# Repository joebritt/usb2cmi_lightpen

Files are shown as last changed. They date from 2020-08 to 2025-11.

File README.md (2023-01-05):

# usb2cmi_lightpen
Use a USB mouse instead of (or in conjunction with) the lightpen on a Fairlight CMI.

<p align="middle">
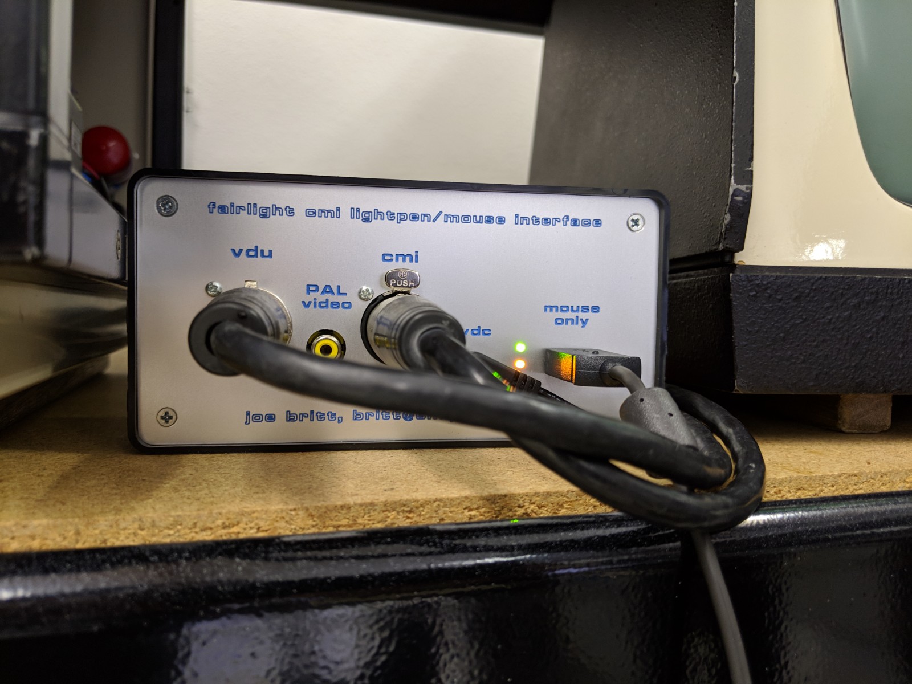
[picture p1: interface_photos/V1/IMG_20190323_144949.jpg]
Version 1
  
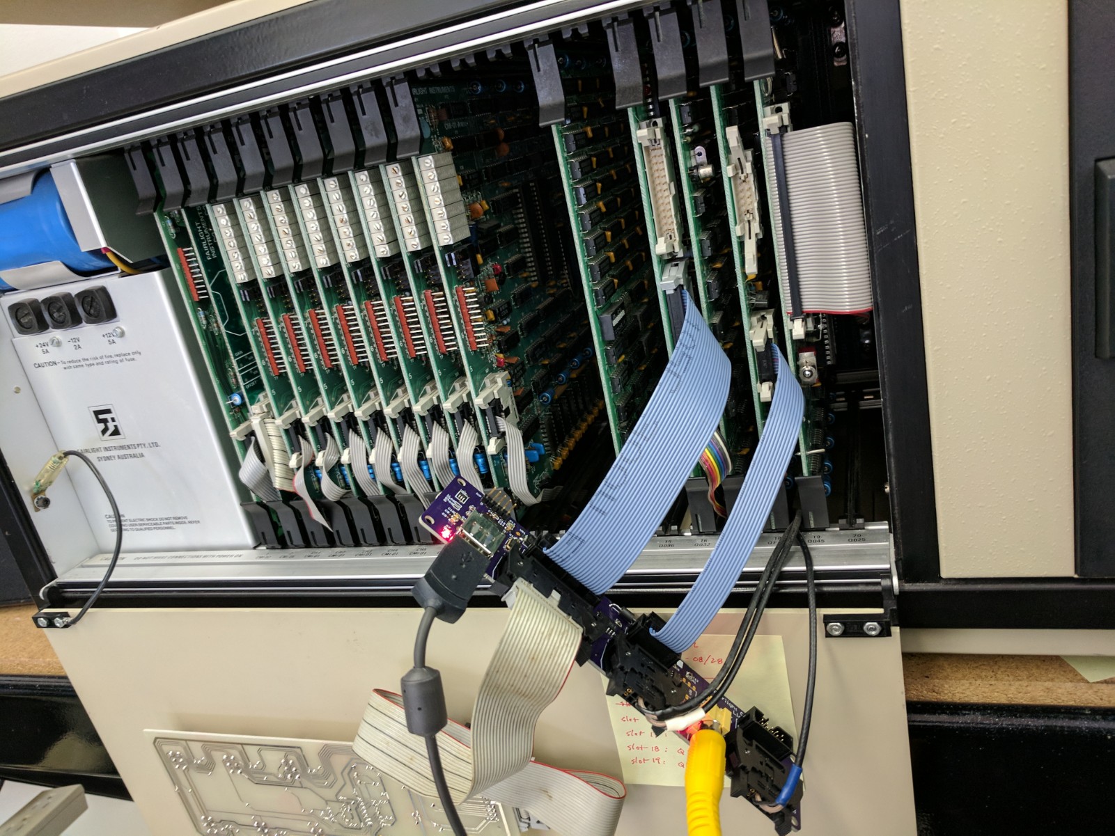
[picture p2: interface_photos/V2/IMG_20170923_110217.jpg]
  
</p>

# Basic Idea

The interface generates lightpen emulation signals that make the CMI video hardware "think" a lightpen is there. The signals are generated to create a small (smaller than is normal with the real lightpen) cursor on the screen.

Moving the mouse, you will see the on-screen cursor track the mouse movement.

Clicking the left button (or button, if it's a 1-button mouse) is like touching the tip of the real lightpen.

If the mouse has a right button, clicking it will toggle the cursor off and on.

If a real lightpen is fitted to the VDU, it will continue to work in conjunction with the mouse.
Normally, the mouse cursor will be shown on the screen. If you bring the lightpen to the screen,
the lightpen cursor will appear and the mouse cursor will disappear. You can then interact using
the lightpen as normal. When you move the lightpen away from the screen, the mouse cursor will
reappear.

# Version 1
[Version 1 PCB](https://oshpark.com/shared_projects/1uISLCAx)</br>

V1 is the original external box style interface. It is powered by a 5V AC adapter.

Both versions have 2 LEDs. These are used to show the status of the video signal (flashes if no video
detected) and presence of a mouse (off if no mouse detected).

V1 has an RCA jack which provides unbuffered access to the CMI video signal. Since it is
unbuffered, the legacy VDU cannot (normally) be used at the same time as the RCA jack.
(V2 buffers the video signal to allow this use case.)

# Version 2
[Version 2 PCB](https://oshpark.com/shared_projects/5qV4mRA7)</br>

V2 is an updated version that fits completely inside the CMI. It is the same core hardware design.

Differences:
  - No AC power supply needed, it is powered from 5V that is tapped from the CMI front panel board
  - RCA jack provides a buffered CMI video signal, so it and the VDU may be used simultaneously
  - Video RCA jack and USB connector are routed to a panel that mounts to the CMI bottom pan
  - laser-cut "wings" attach to the interface board and let it occupy an unused CMI slot

The CMI Series I and II have a slightly different connection to the front panel board. On those
machines, an adapter board is used to convert to a IIX-style connector that the interface board
can connect to.

<p align="middle">
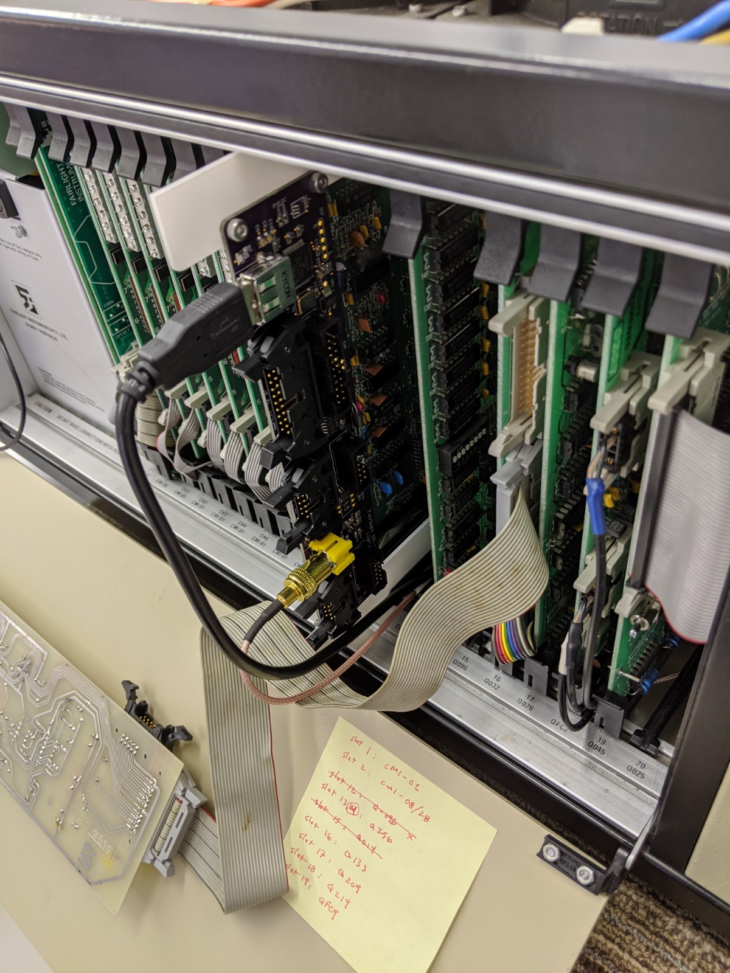
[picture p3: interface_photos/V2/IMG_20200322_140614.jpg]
  
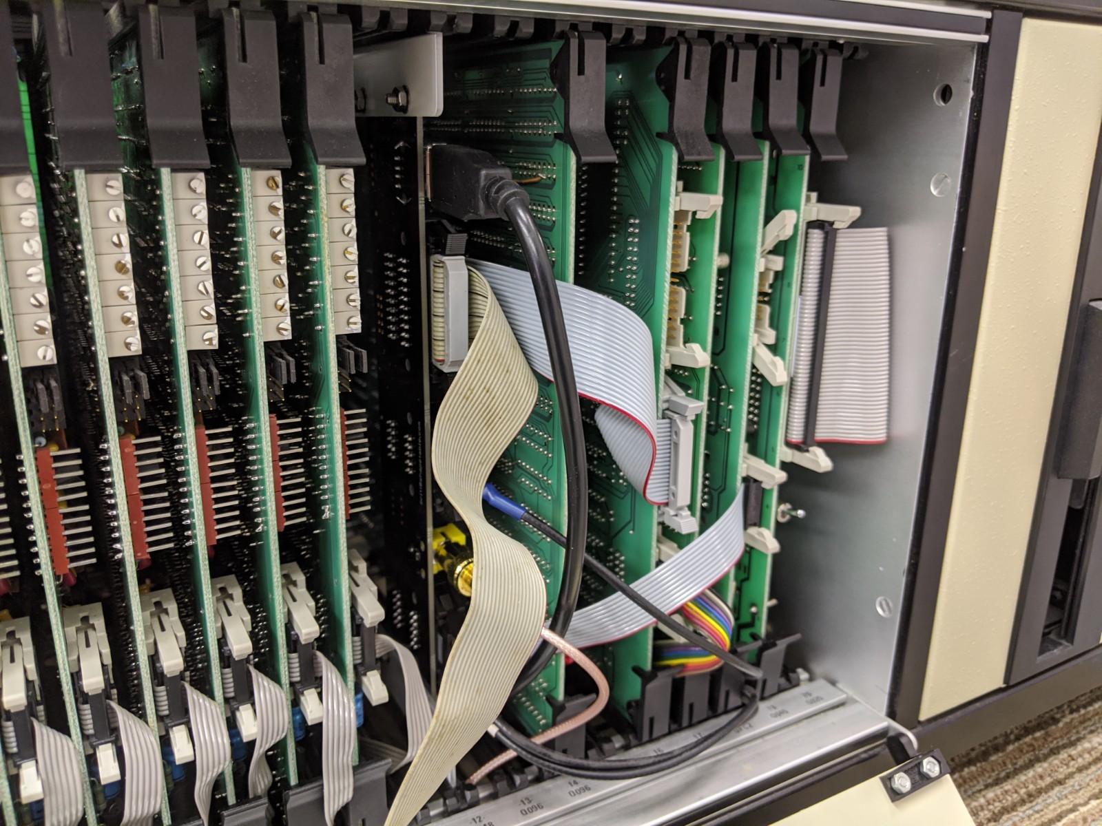
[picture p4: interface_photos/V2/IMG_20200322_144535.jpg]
  
</p>

## Firmware

Some work will be needed to get the code to build with the latest Microchip MPLAB X tools,
so I recommend installing the v8.63 release of MPLAB (pre-MPLAB X). 

Microchip is good about making legacy tools available, you can find version 8.63 here:

https://www.microchip.com/development-tools/pic-and-dspic-downloads-archive

*You don't have to build the code from source:*

In the "prebuilt_hexfiles" folder are pre-compiled images of the bootloader and lightpen emulation application.

To use these:

- Use the Microchip tools to flash bootloader.hex into the PIC32.
- Put cmimouse.hex on a USB thumbdrive (formatted with a DOS/FAT filesystem).
- Plug the thumbdrive into the interface USB port and power up the board.
- You should see the leds blink back and forth, then the cmimouse.hex file will be copied from the thumbdrive to the PIC32 flash.
- You'll see the LEDs change their flashing pattern when the code is flashed and started.
- Unplug the thumbdrive, plug in a mouse, and you should see the mouse status LED turn ON.
- If you connect the unit to the CMI and power on the CMI, you should see the video status LED stop flashing and go solid ON, and the cursor appear on the CMI video output.

## Hardware

The PCB design tool Eagle was used for all PCBs. 
The Eagle .brd files can be easily uploaded to OSHPark (https://oshpark.com/) for fabrication. Of course, you can use any board house you like to make them.
All boards are 2 layer, 6mil minimum trace/space, and 10mil minimum drill.

The aluminum front panel (for Version 1) and the aluminum rear panel (for Version 2) were designed using Front Panel Designer and fabricated using Front Panel Express (https://www.frontpanelexpress.com/).
Eagle was used as a crude 2D mechanical CAD for the Version 2 rear panel and the Version 2 mounting wings. 
Board files and generated PDFs and XPS files for these are included. The XPS files were used to drive a laser cutter to make prototypes of the rear panel and to make the actual mounting wings.

## Cabling

### Version 1

The 5-pin XLR cable from the CMI to the monitor ("VDU" in Fairlight parlance) connects
to the box. This cable carries a monochrome composite video signal with PAL timing from the CMI
and 2 TTL level signals from the lightpen to the CMI. 

These 3 signals are carried over 3x 75 ohm coax cables bundled together and sheathed similar to
an analog RGB video cable. The pinout for this cable is not straight-through, please see the
details in the monitor_cable folder.

Using two of these 5-pin XLR cables, the box is connected between the CMI and VDU.
Of course, the box can be used without the VDU, in which case only one 5-pin XLR cable is needed.

### Version 2

Version 2 doesn't need the external 5-pin XLR cabling, but does need several smaller internal cables:

- 1x 26-way ribbon cable with a female IDC connector at each end, taps power from CMI front panel
- 1x (CMI IIX) or 2x (CMI I or II) 10-way ribbon cable with a female IDC connector at each end for video & LP signals
- 1x USB Type A to Type B bulkead connector extension, routes USB connection on board to rear panel
- 1x RCA male/male extension, routes video from RCA jack on board to rear panel RCA jack
- 1x RCA female/female bulkhead connector, pass video from internal extension cable to external jack

## Mounting Hardware

### Version 1

The plastic box that was used for Version 1 is off-the-shelf from Radio Shack. It appears that they
still carry this box: https://www.radioshack.com/products/radioshack-project-enclosure-6x3x2?variant=20332261445

The aluminum front panel is designed to replace the blank aluminum panel that comes with the box.

The PCB attaches to the aluminum front panel with the 4 XLR connector screws and floats inside the box.

### Version 2

The 2 laser-cut plastic wings attach to the PCB with 4x M3 screws, nuts, and lockwashers. There are 2 versions
of the wings -- I thought the originals were a little too long, so I made a version 1cm shorter. Both work fine, but the longer ones may cause the internal USB connector to rub against the inside of the front panel door.

For the rear panel, countersunk holes are provided in the aluminum panel to accept the screws originally used to hold the Fairlight factory-provided blank cover panel. Remove the blank panel, use the screws and nuts to affix the new aluminum video/USB jack panel.

The bulkhead female/female RCA connector has 1 large nut which should be on the inside face of the panel.
The bulkhead USB connector has 2 M3 screws that hold it in place.

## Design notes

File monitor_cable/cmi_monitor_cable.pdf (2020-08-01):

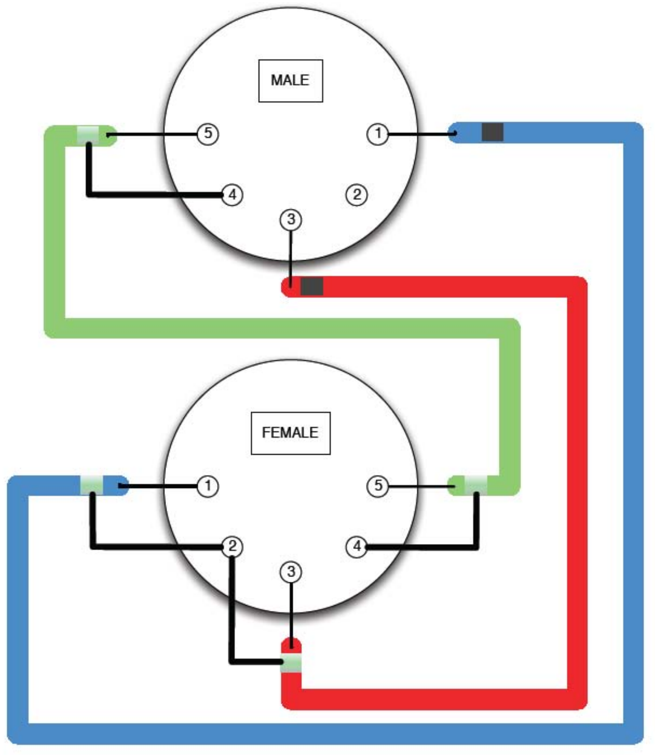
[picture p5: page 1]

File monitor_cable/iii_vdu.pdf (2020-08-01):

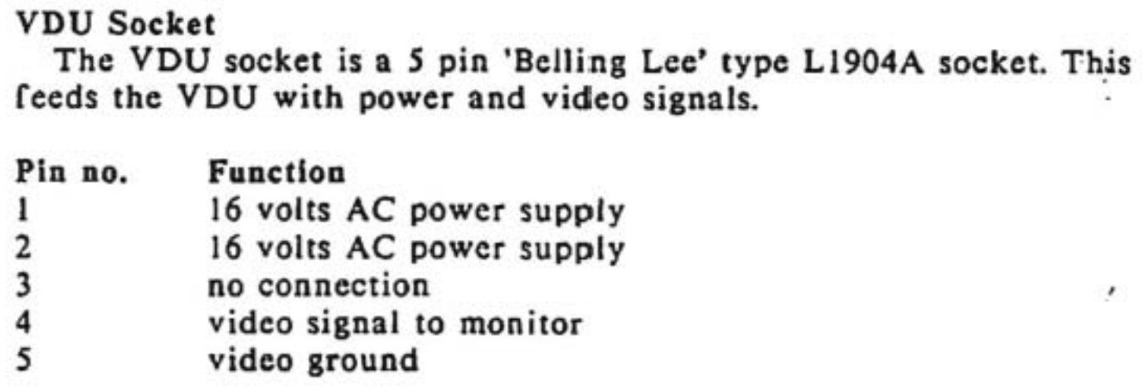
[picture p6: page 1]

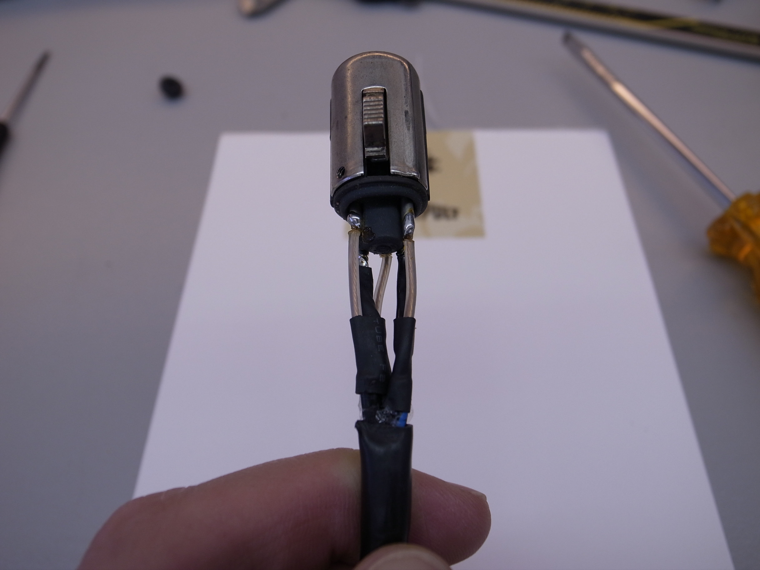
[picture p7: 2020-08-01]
monitor_cable/F_XLR5_BRITT_2.jpg

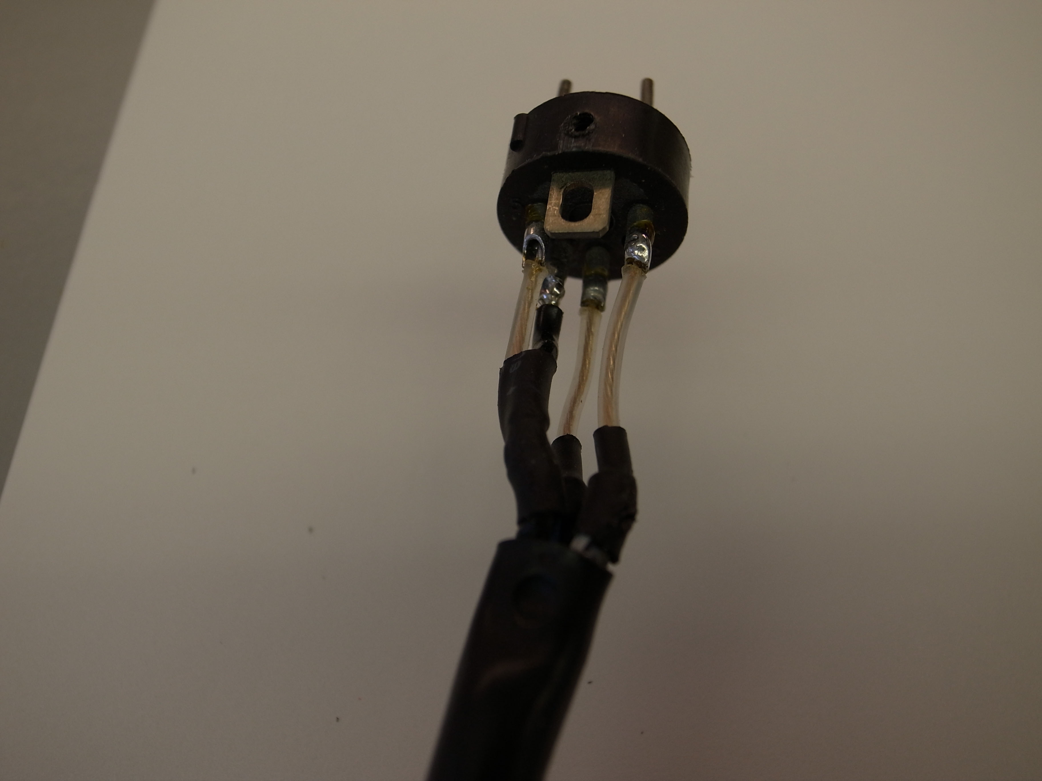
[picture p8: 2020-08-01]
monitor_cable/M_XLR5_BRITT_2.jpg

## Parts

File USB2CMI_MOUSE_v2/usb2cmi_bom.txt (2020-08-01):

	total boards:	20						
								
shortfall	on hand	total	per board					
		Qty	Qty	Value	Device	Parts	supplier	NOTES
11	9	20	1		L-US0207/15	FB1	HSC	
0	20	20	1		MA20-2 *NOTE*	EXP	personal surplus	"mount 2x 5 pin header at pin 1, cut down longer ones"
116	84	200	10	.1uF	C_0603	"C1, C2, C3, C4, C5, C6, C9, C10, C11, C21"	HSC	
0	28	20	1	0	R_0603	R16	HSC	
11	9	20	1	1N4002	1N4002	D1	HSC	
16	4	20	1	8 MHz	CTS-OSC	X1	Mouser	
0	29	20	1	10K	R_0603	R12	HSC	
0	80	40	2	33uF	CPOL-US085CS-1AR	"C7, C22"	personal surplus	
0	29	20	1	51	R_0603	R7	HSC	
0	29	20	1	56	R_0603	R6	HSC	
16	4	20	1	74LS00D	74LS00D	U2	"HSC, Mouser"	
20	0	20	1	100uF	CPOL-USCT6032	C8	Mouser	
0	57	40	2	220	R_0603	"R3, R5"	HSC	
0	57	40	2	330	R_0603	"R2, R4"	HSC	
20	0	20	1	680K	R_0603	R1	HSC	
0	59	20	1	DANGER_POWER	DANGER_POWER	J4	personal surplus	
0	34	20	1	HSC_STACKED	HSC_STACKED	LED1	HSC	
								
20	0	20	1	LM1881SO	LM1881SO	U3B	"Jameco, Digikey, Mouser"	
6	14	20	1	LT1963A-3.3	LINEAR-REG-SOT223	VR1	Digikey	LT1963AEST-3.3#PBF-ND
11	9	20	1	NC5FAH	NC5FAH	J2		
11	9	20	1	NC5MBH	NC5MBH	J1		
12	8	20	1	PIC32MX440FH	PIC32MX440FH	U1		
0	24	20	1	RCA-HSC	RCA-HSC	J3		
0	34	20	1	RJ11	RJ11	ICP		
								
20	0	20	1	TPS2051BDBV	TPS2041BDBV	U5B	Mouser	
20	0	20	1	USB-A-H	USB-A-H	J5

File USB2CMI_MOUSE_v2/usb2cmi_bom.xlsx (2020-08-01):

per board
Qty | digikey | Value | Device | Parts | NOTES
1 |  |  | L-US0207/15 | FB1
10 | 490-5881-1-ND (http://www.digikey.com/scripts/DkSearch/dksus.dll?Detail&itemSeq=226131515&uq=636285868996329209) | .1uF | C_0603 | C1, C2, C3, C4, C5, C6, C9, C10, C11, C21
3 | 311-0.0GRCT-ND (http://www.digikey.com/scripts/DkSearch/dksus.dll?Detail&itemSeq=226131532&uq=636285868996329209) | 0 | R_0603 | R16, R8, R9
1 | CTX301LVCT-ND (http://www.digikey.com/scripts/DkSearch/dksus.dll?Detail&itemSeq=226131551&uq=636285868996329209) | 8 MHz | CTS-OSC | X1
1 | P10KAGCT-ND (http://www.digikey.com/scripts/DkSearch/dksus.dll?Detail&itemSeq=226131872&uq=636285875494800644) | 10K | R_0603 | R12
2 |  | 33uF | CPOL-US085CS-1AR | C7, C22
2 | P56GCT-ND (http://www.digikey.com/scripts/DkSearch/dksus.dll?Detail&itemSeq=226131893&uq=636285875946559209) | 56 | R_0603 | R6, R7
1 | 296-14873-1-ND (http://www.digikey.com/scripts/DkSearch/dksus.dll?Detail&itemSeq=226131851&uq=636285874587879961) | 74LS00D | 74LS00D | U2
1 |  | 100uF | CPOL-USCT6032 | C8
2 | P220GCT-ND (http://www.digikey.com/scripts/DkSearch/dksus.dll?Detail&itemSeq=226131961&uq=636285877032814430) | 220 | R_0603 | R3, R5
2 | P330GCT-ND (http://www.digikey.com/scripts/DkSearch/dksus.dll?Detail&itemSeq=226131964&uq=636285877272659209) | 330 | R_0603 | R2, R4
1 | P680KGCT-ND (http://www.digikey.com/scripts/DkSearch/dksus.dll?Detail&itemSeq=226131969&uq=636285877573828526) | 680K | R_0603 | R1
1 | 609-4616-1-ND (http://www.digikey.com/scripts/DkSearch/dksus.dll?Detail&itemSeq=226131568&uq=636285868996339209) | FCI 10118193-0001LF | Micro USB | J4
1 | 350-1823-ND (http://www.digikey.com/scripts/DkSearch/dksus.dll?Detail&itemSeq=226131790&uq=636285874161180812) | 5530123F | Dialight 2 high LED | LED1
1 | LM1881N/NOPB-ND (http://www.digikey.com/scripts/DkSearch/dksus.dll?Detail&itemSeq=226131589&uq=636285870148726090) | LM1881SO | LM1881SO | U3B
1 | LT1963AEST-3.3#TRPBFCT-ND (http://www.digikey.com/scripts/DkSearch/dksus.dll?Detail&itemSeq=226131603&uq=636285870685653294) | LT1963A-3.3 | LINEAR-REG-SOT223 | VR1 | LT1963AEST-3.3#PBF-ND/ cheaper one is AME
1 |  | NC5FAH | NC5FAH | J2
1 |  | NC5MBH | NC5MBH | J1
1 | PIC32MX440F128H-80I/PT-ND (http://www.digikey.com/scripts/DkSearch/dksus.dll?Detail&itemSeq=226131780&uq=636285873862370934) | PIC32MX440FH | PIC32MX440FH | U1
1 | CP-1421-ND (http://www.digikey.com/scripts/DkSearch/dksus.dll?Detail&itemSeq=226131634&uq=636285871022663475) | RCJ-044 | CUI RCA | J3
1 | 553-2258-ND (http://www.digikey.com/scripts/DkSearch/dksus.dll?Detail&itemSeq=226131638&uq=636285871313076030) | E5566-Q0LK22-L | PULSE RJ11 | ICP
1 |  |  | MA20-2 *NOTE* | EXP | mount 2x 5 pin header at pin 1, cut down longer ones
1 |  | TPS2051BDBV | TPS2041BDBV | U5B
1 |  | USB-A-H | USB-A-H | J5
1 |  | radio shack case

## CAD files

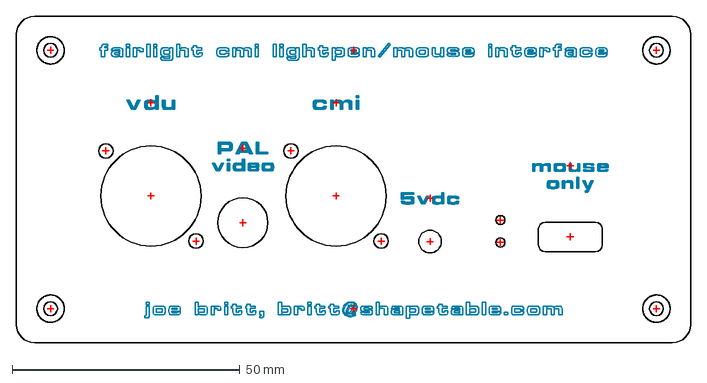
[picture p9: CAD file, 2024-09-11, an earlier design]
USB2CMI_MOUSE_v1/USB2CMI_log.dxf
148.0 x 71.7 mm

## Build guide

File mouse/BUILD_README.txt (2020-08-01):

Building USB Mouse -> CMI Lightpen adapter code
Joe Britt, August 2010

BUILDING FOR/WITH BOOTLOADER
----------------------------

Build the bootloader project (Release build) and flash into PIC32440MX128H
using ICD3 or equivalent.

Build the mouse project (Release build).  Do not flash.  Switch to command
(DOS) window and go to the mouse\Output directory.

type:

pic32-bin2hex -v cmi_mouse.elf

then type:

rename cmi_mouse.hex cmimouse.hex

then copy cmimouse.hex to your USB thumbdrive.

Plug USB thumbdrive into usb2cmi mouse adapter USB port, and power cycle the
usb2cmi board.  You will see the yellow light flicker as the mouse application
is programmed into the application partition.  When it finishes, it will
start the mouse application.

BUILDING STANDALONG (NO BOOTLOADER)
-----------------------------------

Open the mouse project and remove the 2 Linker Script files (in the IDE).
Build and load onto the usb2cmi board with an ICD3 or equivalent.

Debug/run.

Note that this will overwrite the bootloader, so you will need to build
and re-flash it if you want/need to use it again.

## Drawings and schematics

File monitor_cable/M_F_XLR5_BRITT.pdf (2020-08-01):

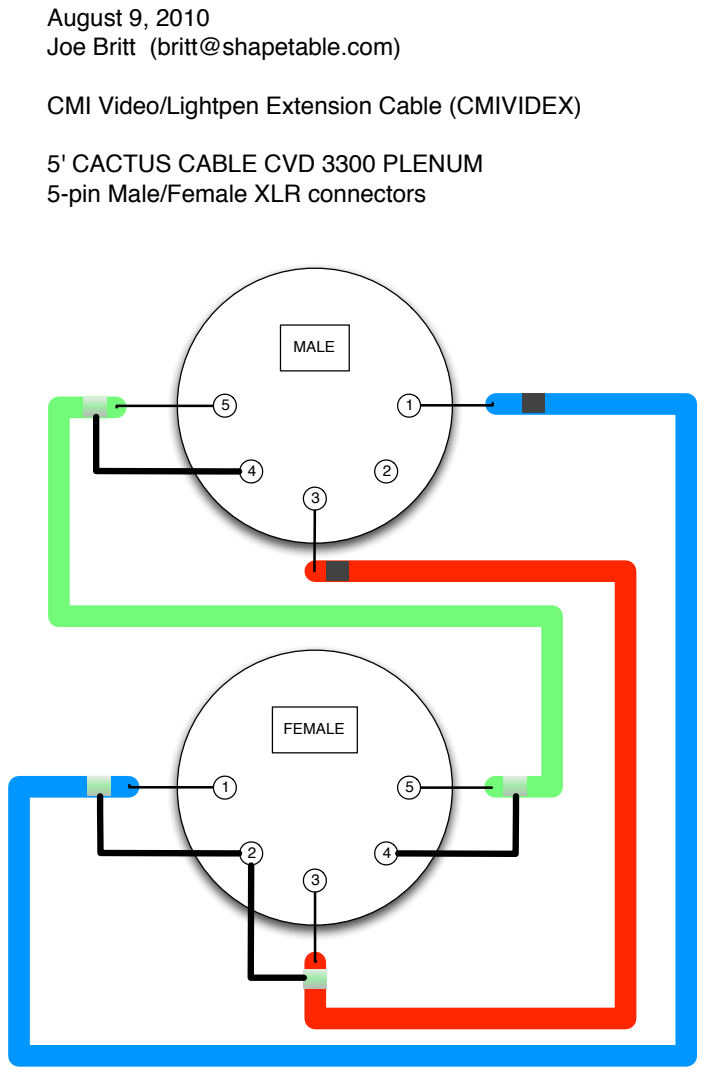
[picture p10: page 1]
MALE; FEMALE

August 9, 2010
Joe Britt (britt@shapetable.com)

CMI Video/Lightpen Extension Cable (CMIVIDEX)

5' CACTUS CABLE CVD 3300 PLENUM
5-pin Male/Female XLR connectors

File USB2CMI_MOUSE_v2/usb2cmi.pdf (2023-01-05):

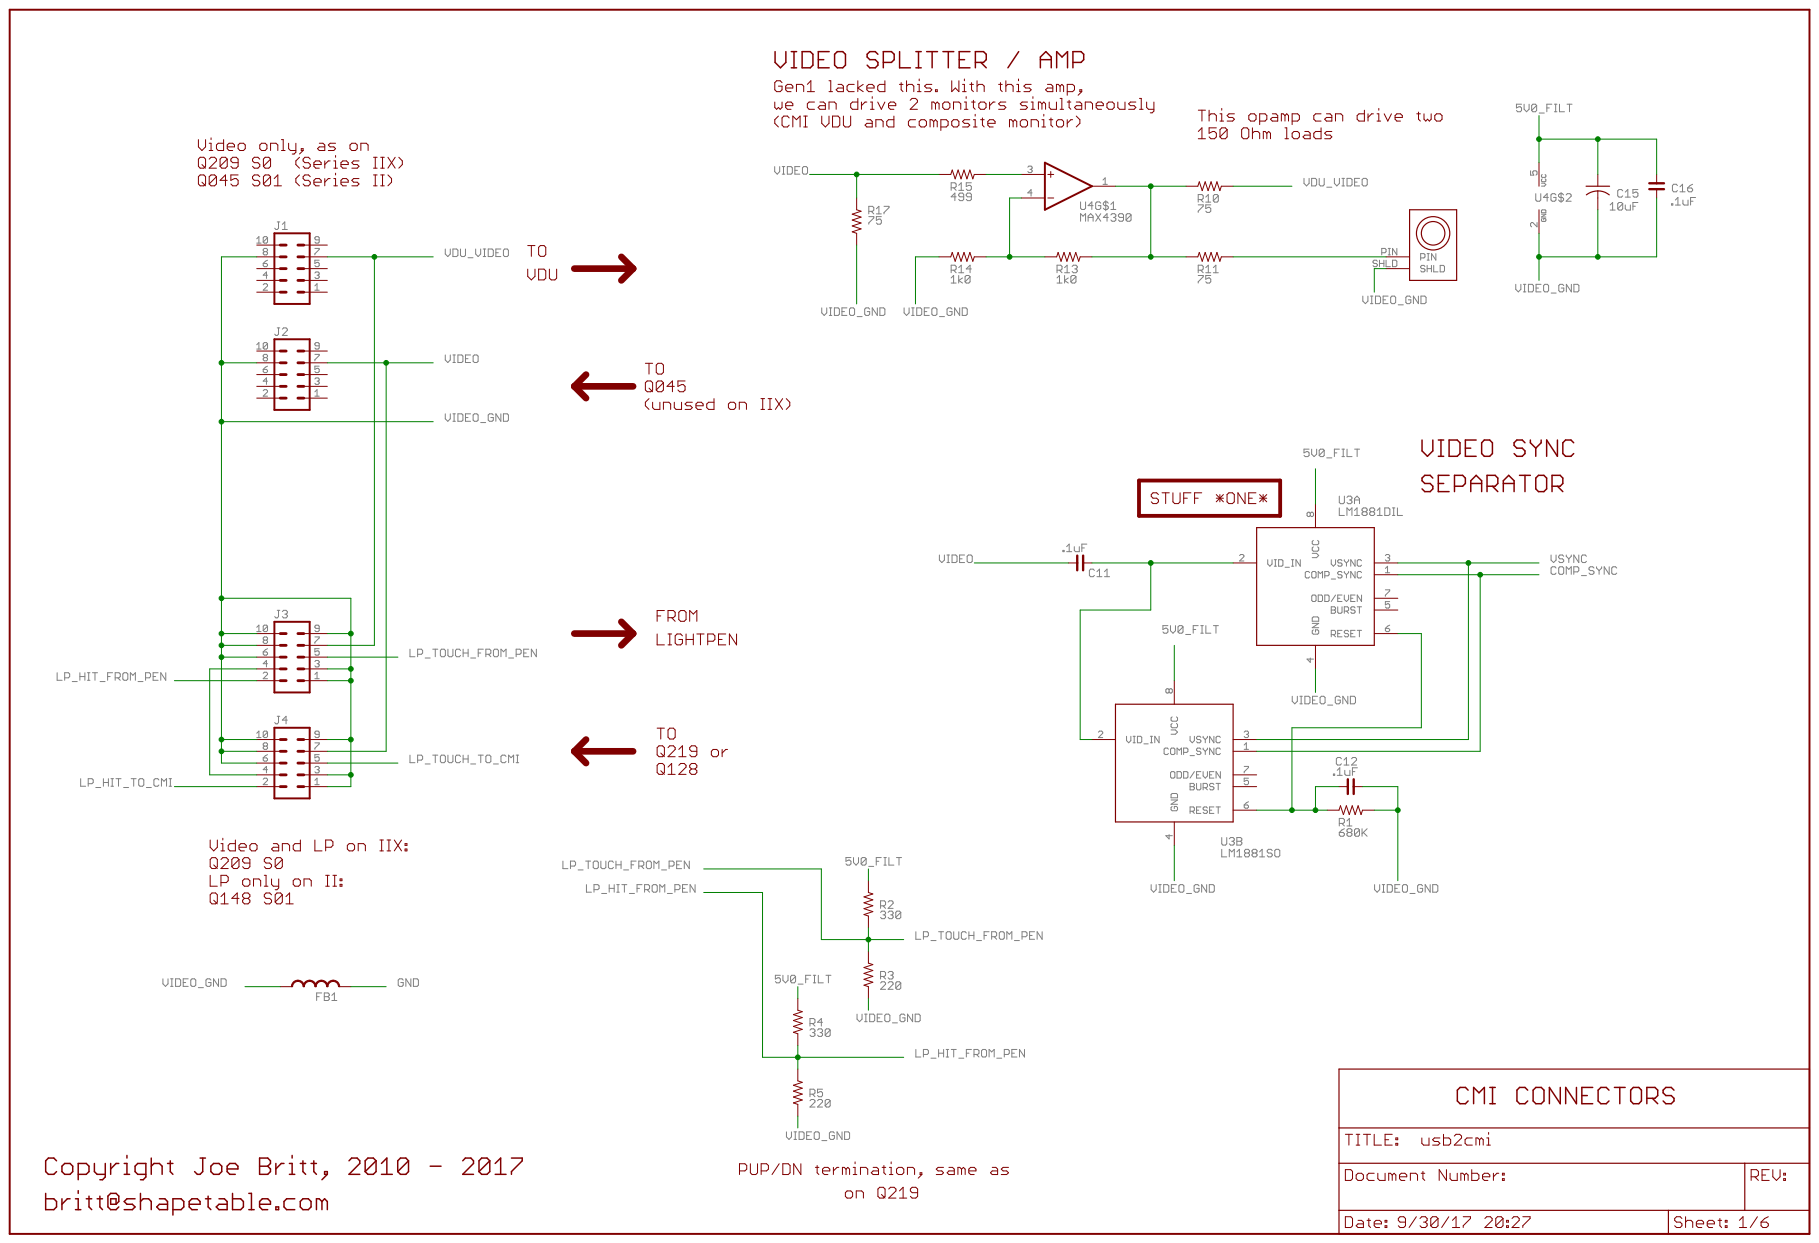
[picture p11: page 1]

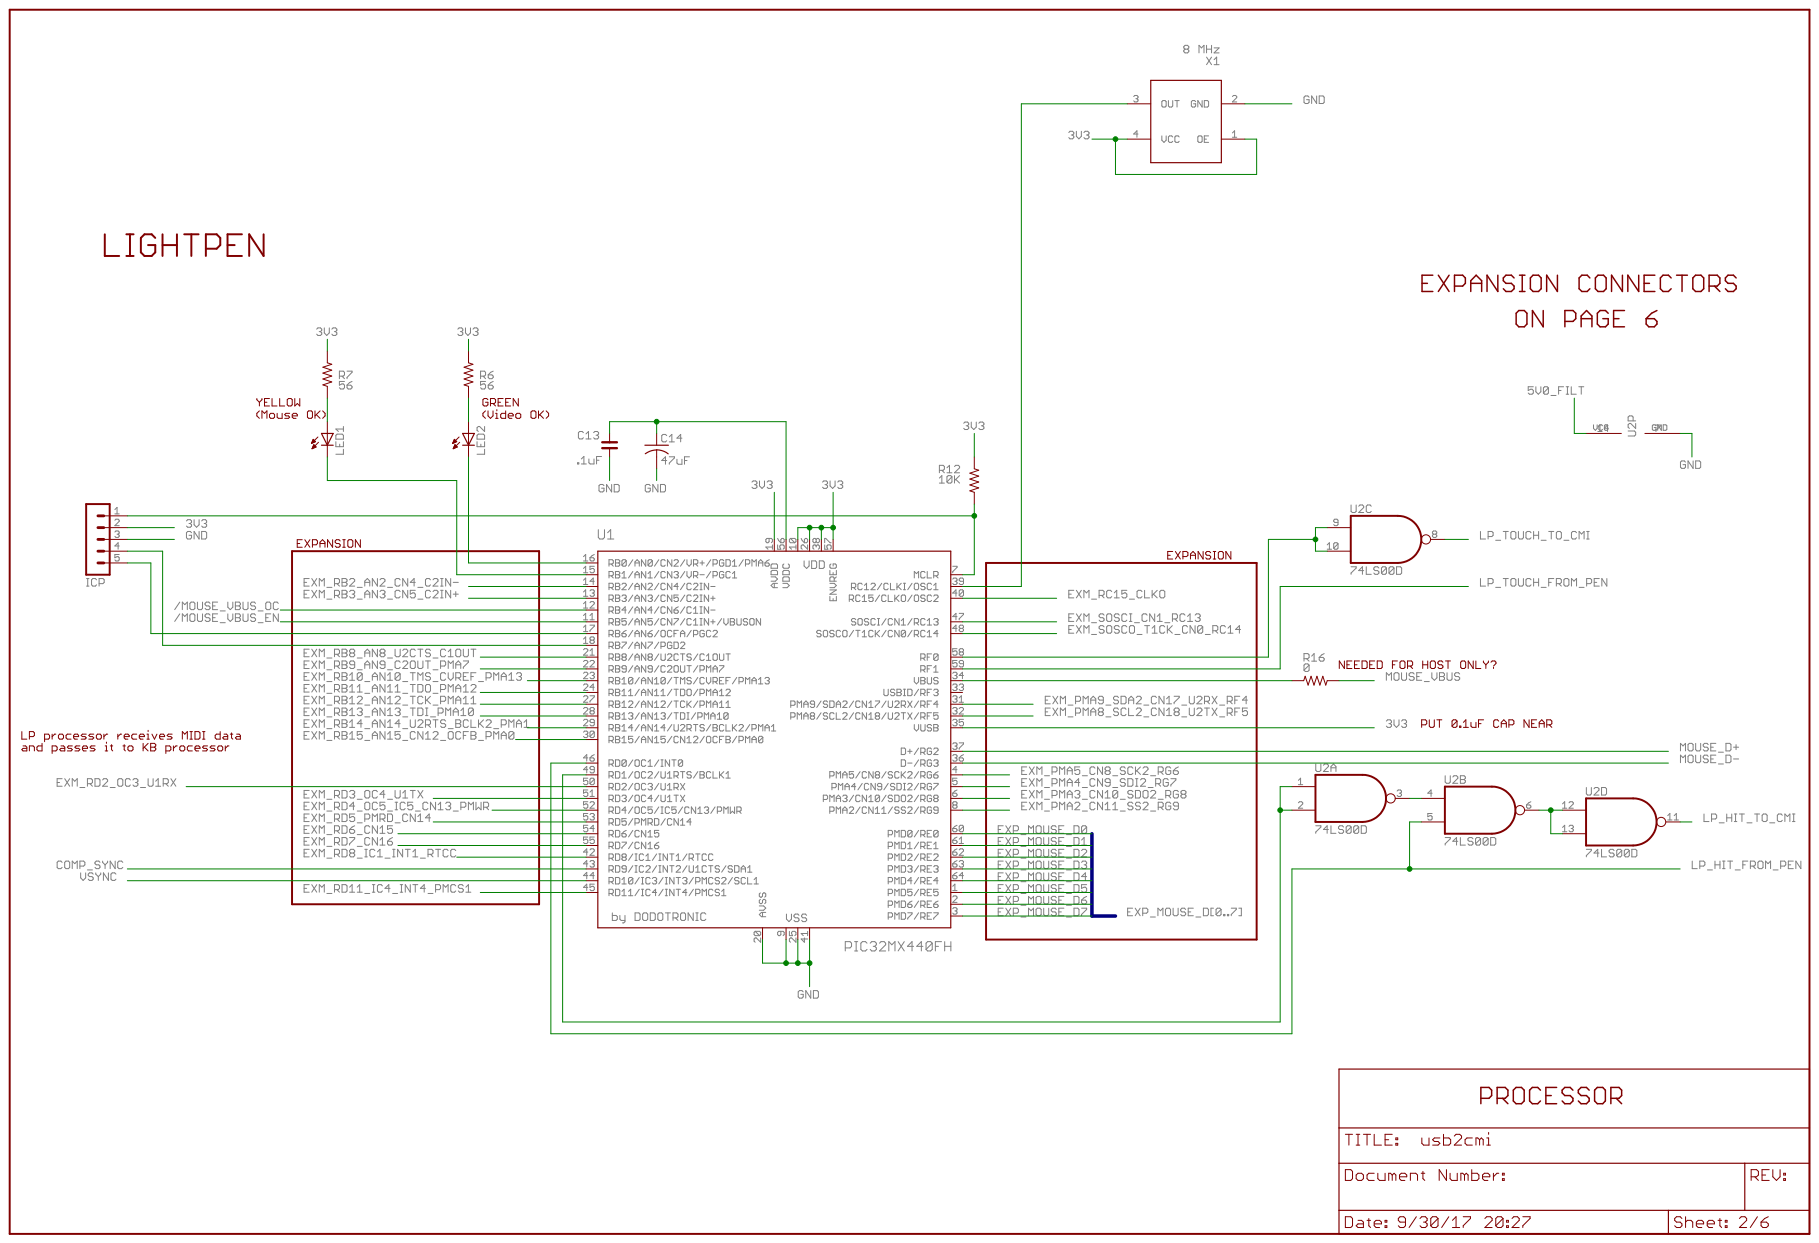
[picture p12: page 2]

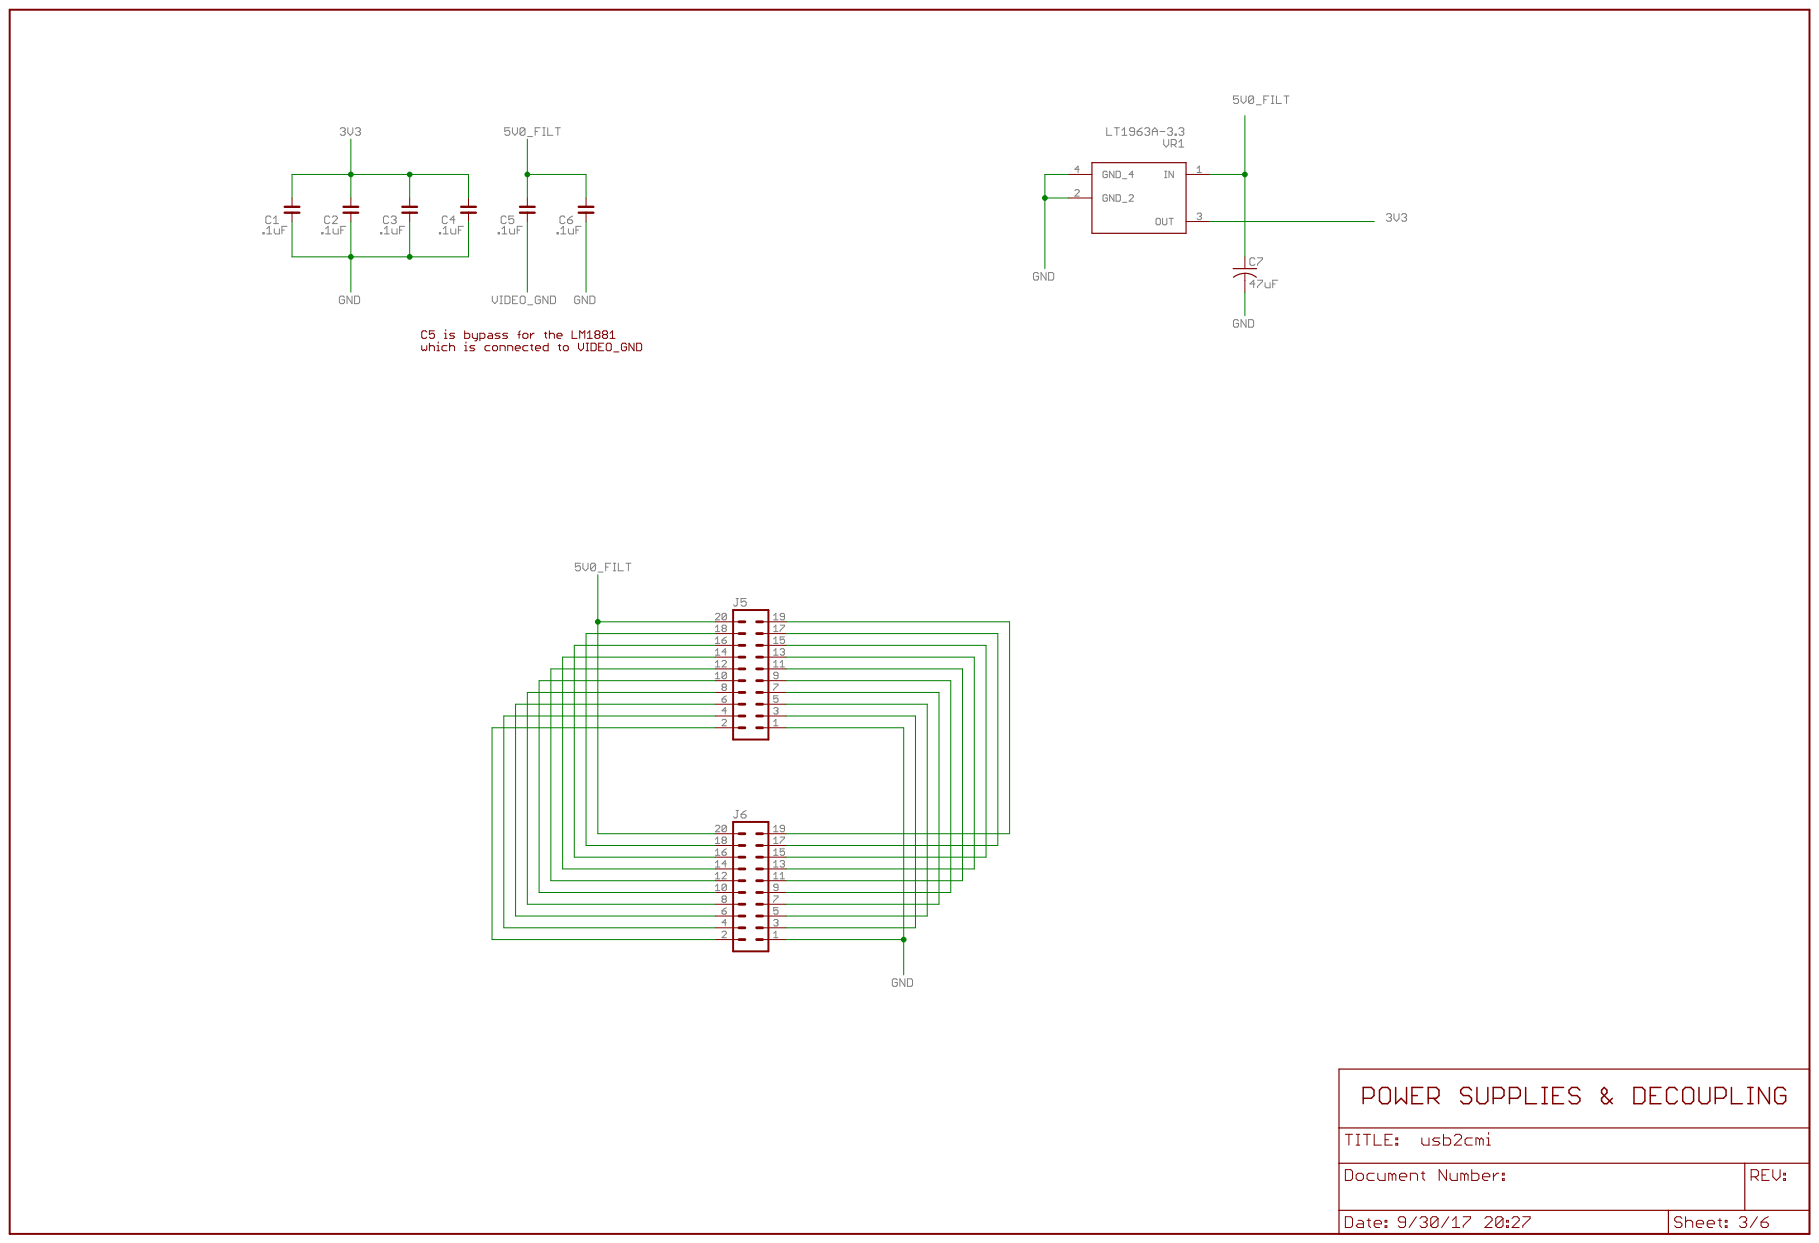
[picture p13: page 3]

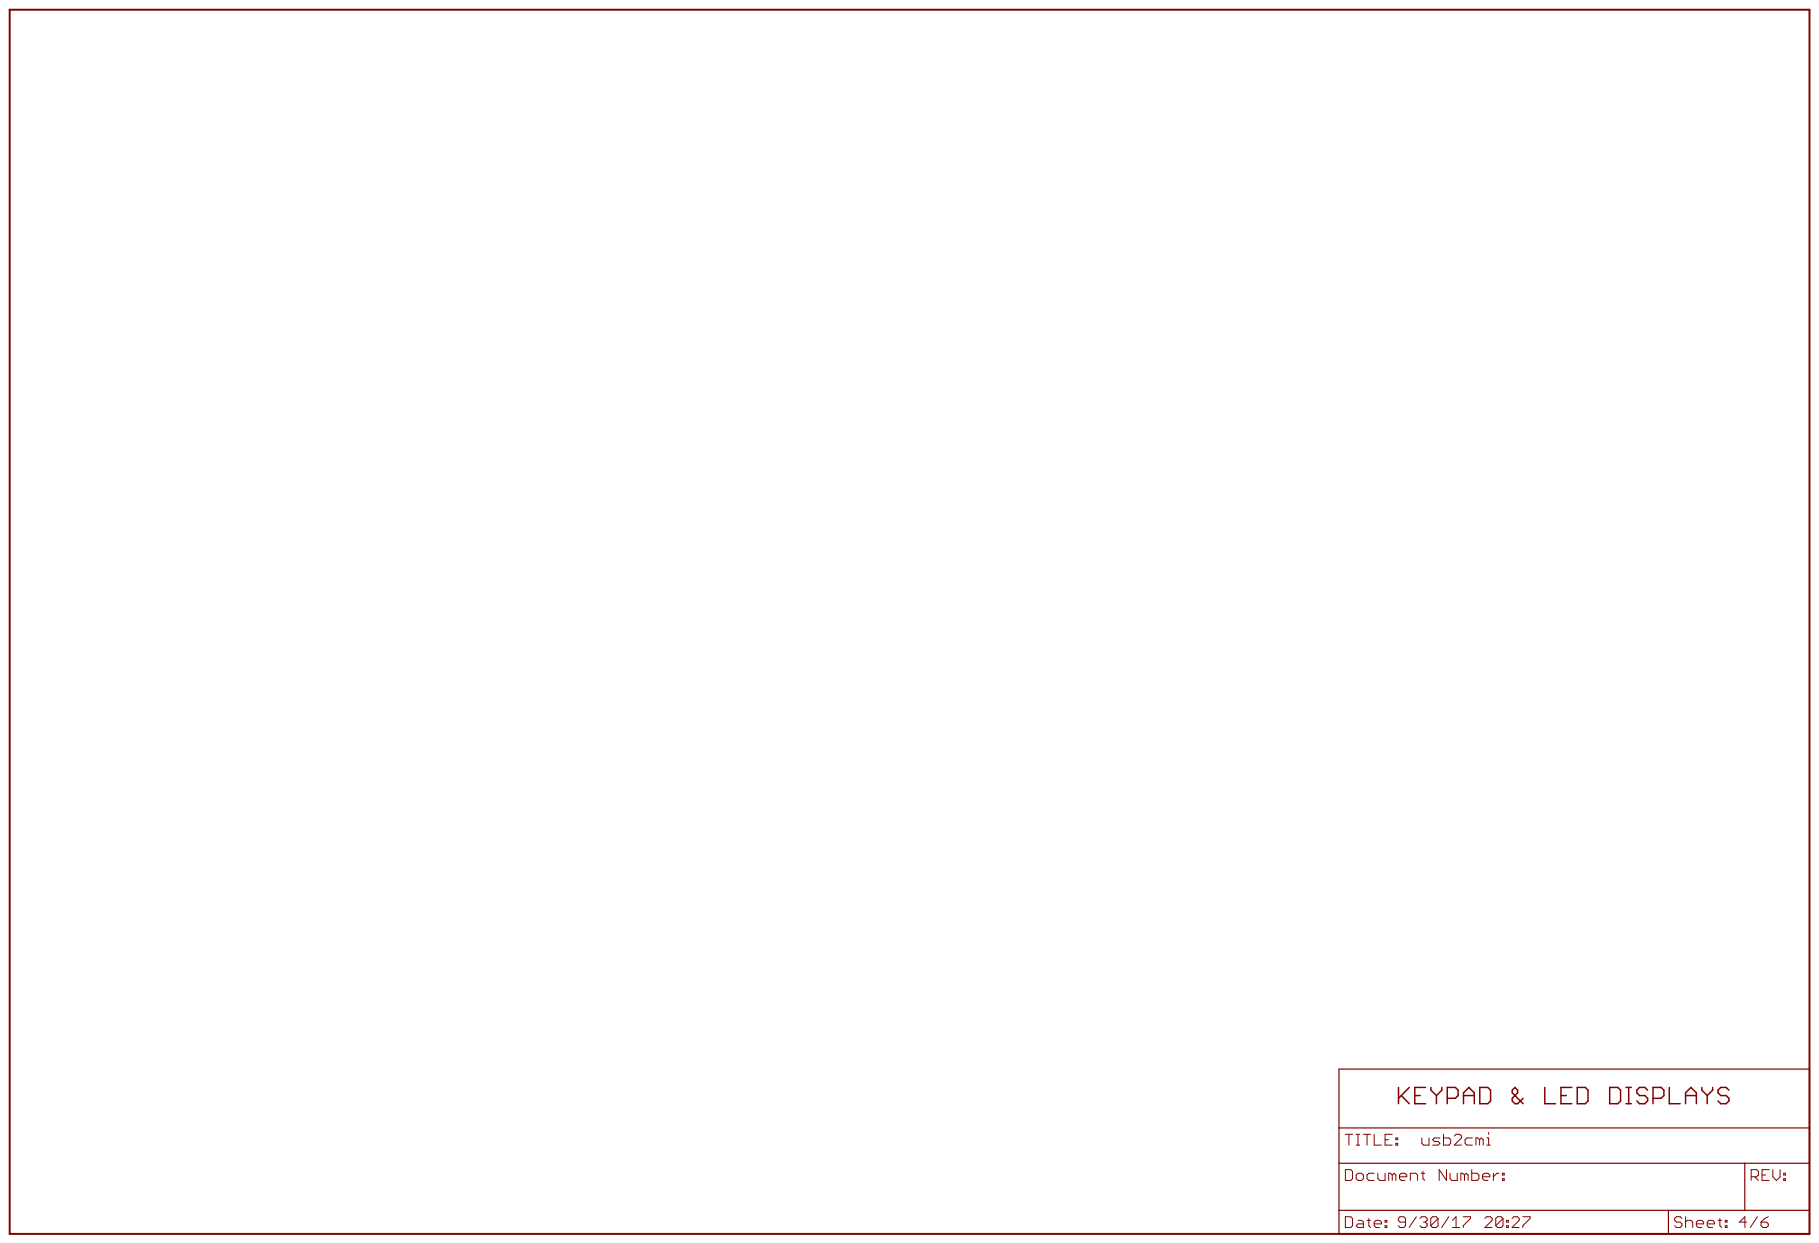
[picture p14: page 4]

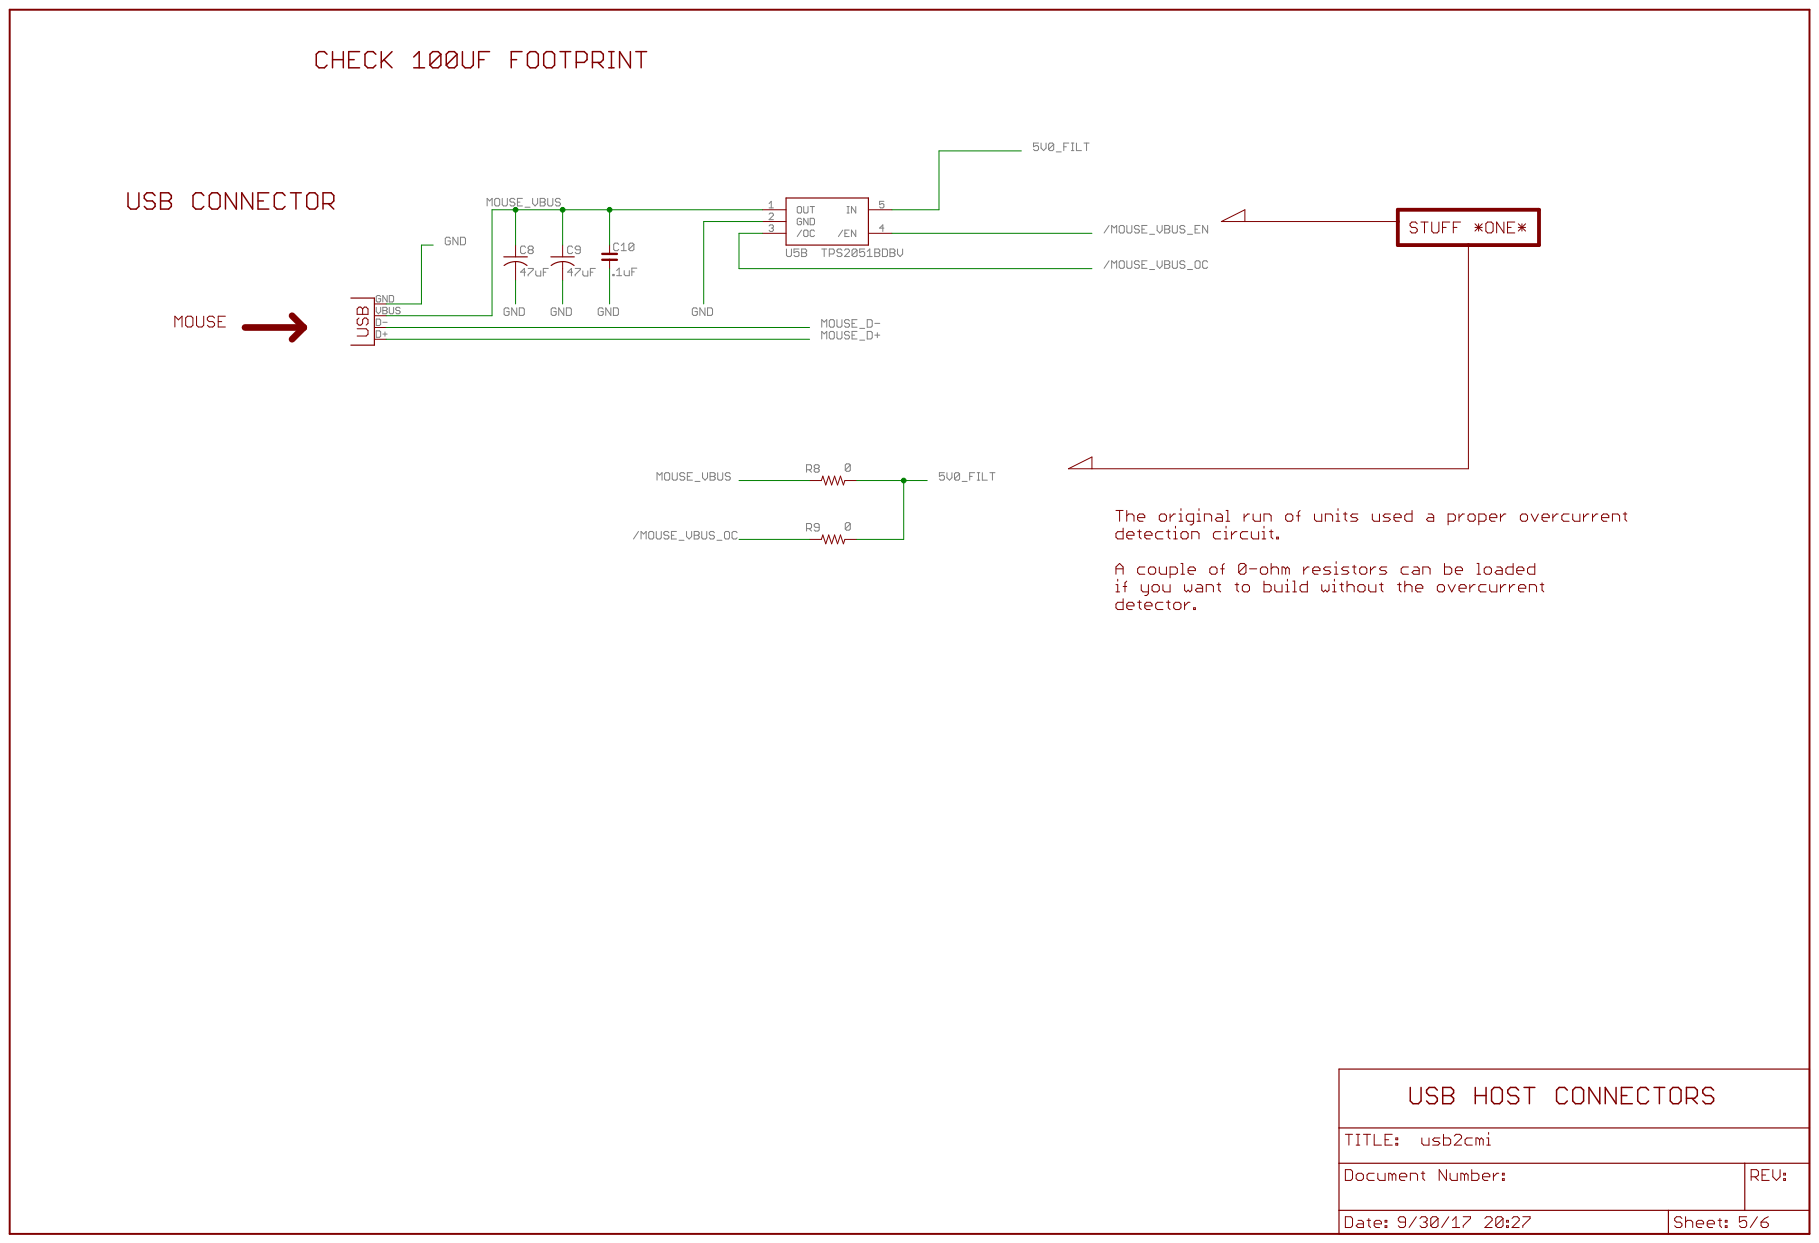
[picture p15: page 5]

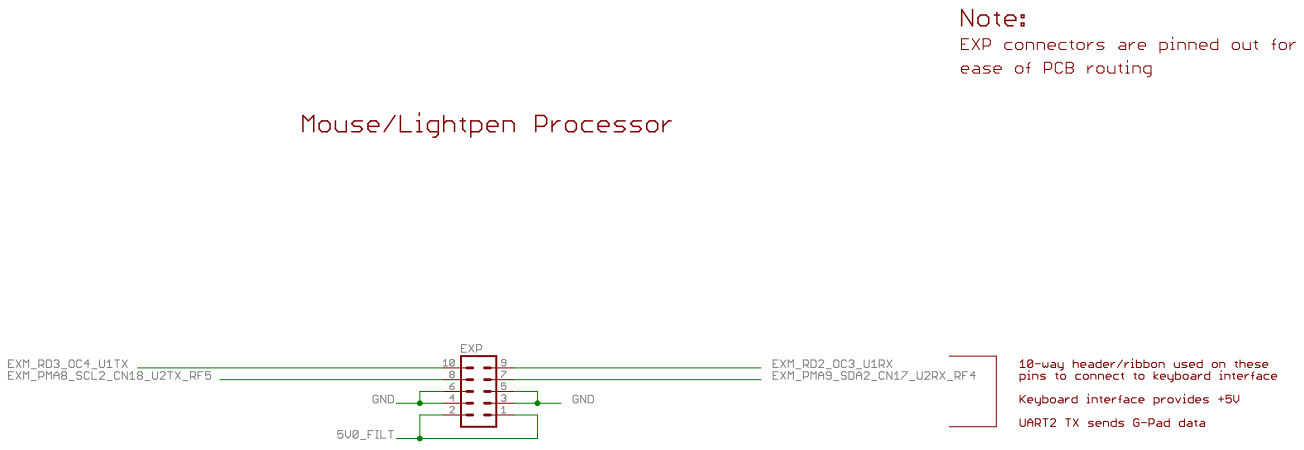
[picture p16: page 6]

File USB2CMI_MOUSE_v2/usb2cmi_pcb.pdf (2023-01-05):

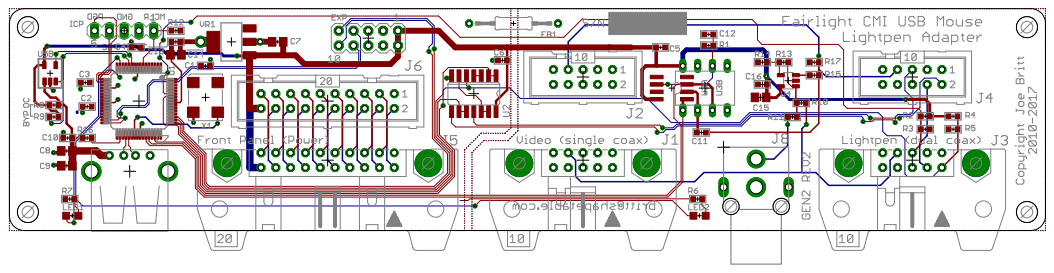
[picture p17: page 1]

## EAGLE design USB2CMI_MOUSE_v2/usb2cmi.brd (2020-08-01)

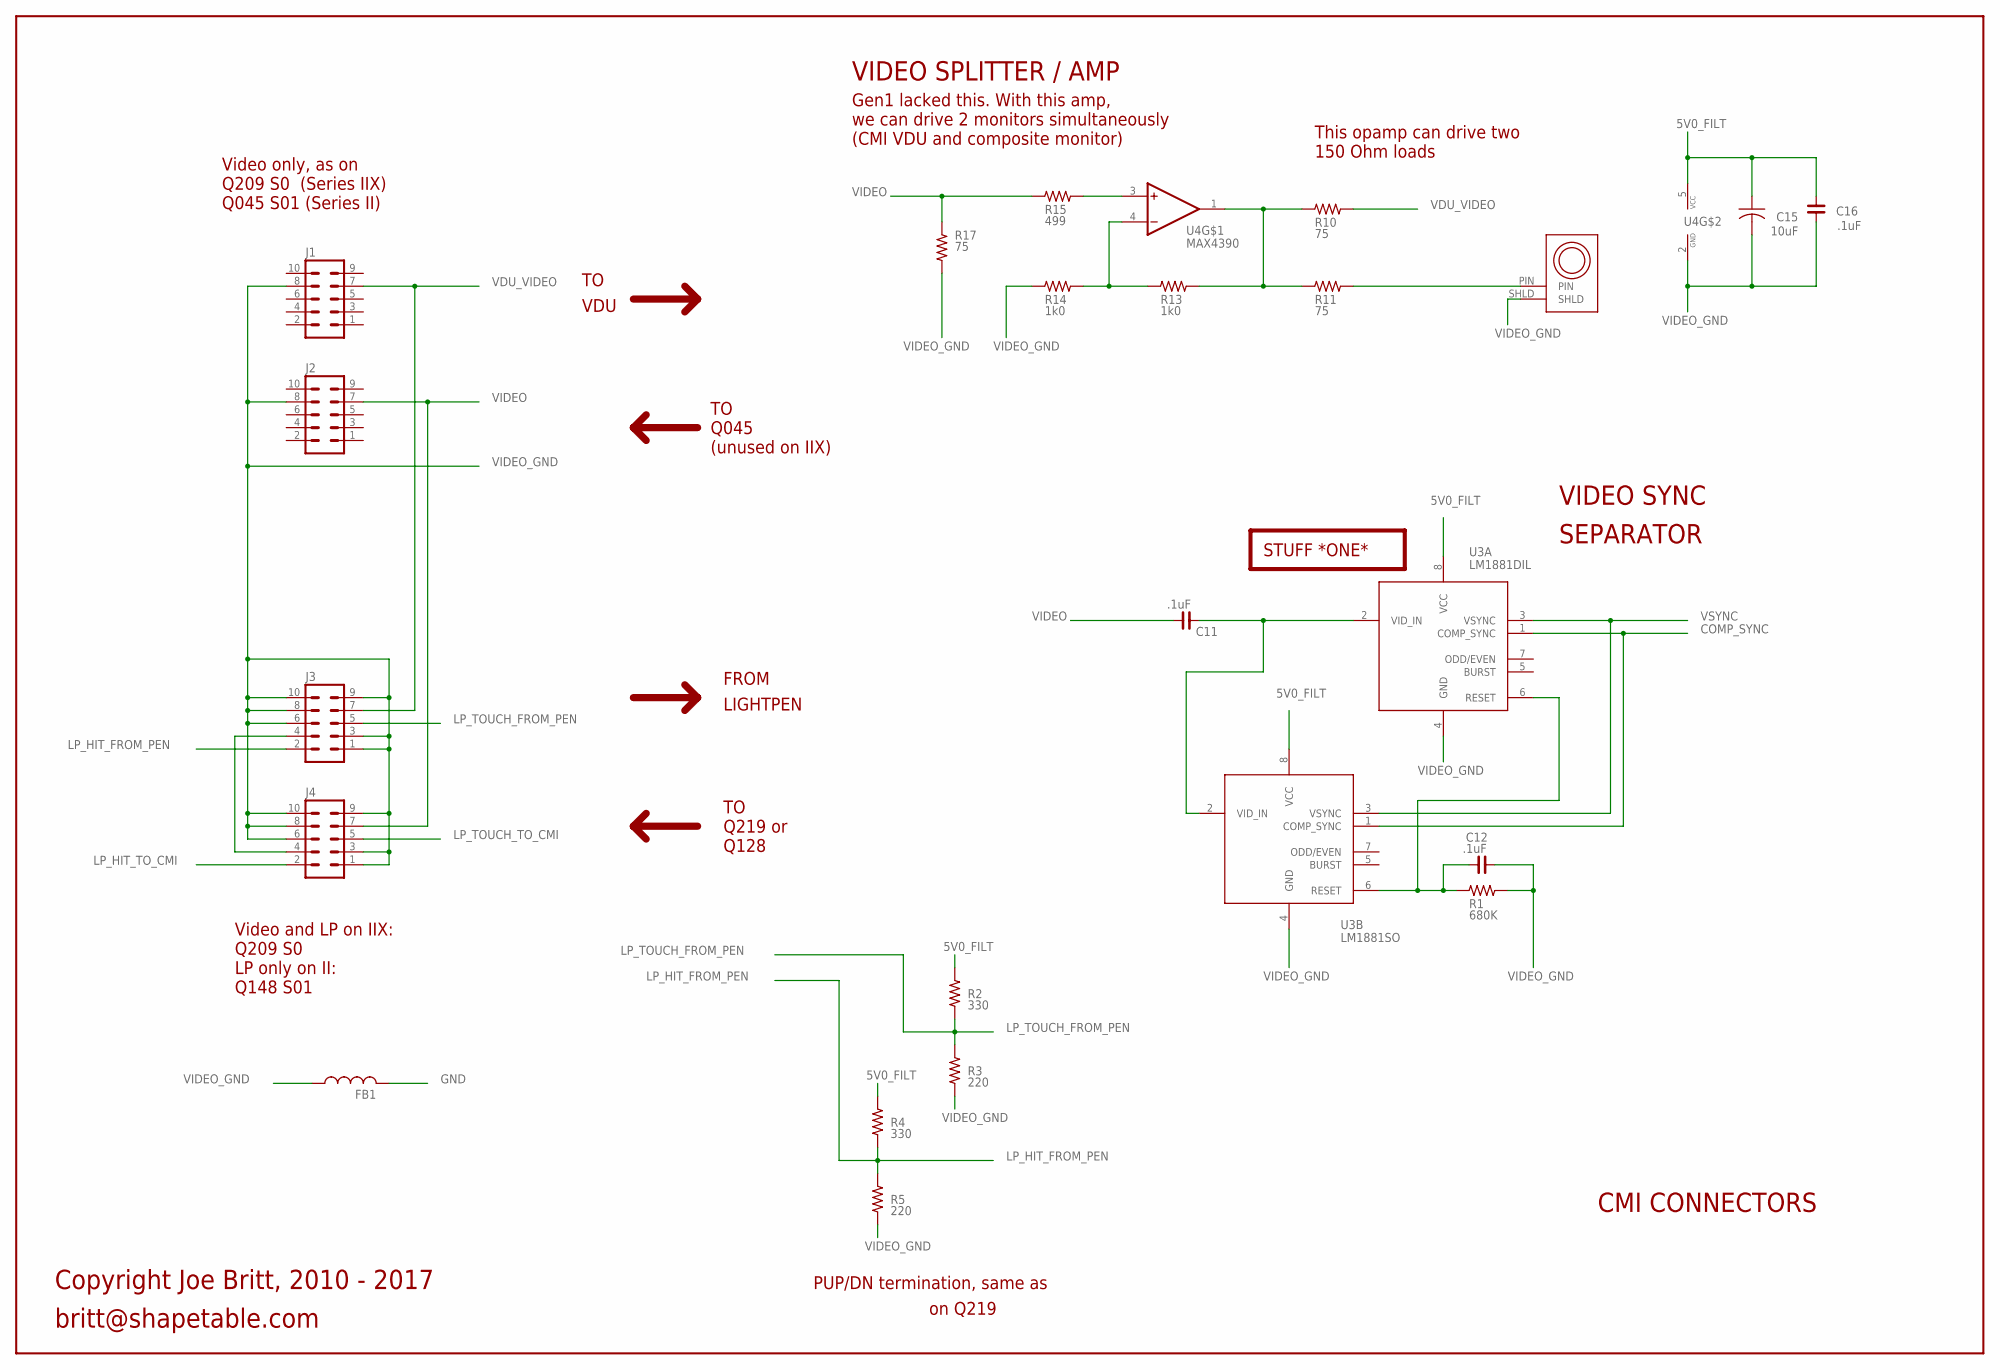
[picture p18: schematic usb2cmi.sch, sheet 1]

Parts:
C11, C12, C16: .1uF; C0603
C15: 10uF; C0805
FB1: L-US0207/15; 0207/15
J1, J3: 10H
J2, J4: ML10
J8: CUI RCJ-044; RCA-SHIELDED
R1: 680K; R0603
R2, R4: 330; R0603
R3, R5: 220; R0603
R10, R11, R17: 75; R0603
R13, R14: 1k0; R0603
R15: 499; R0603
U3A: LM1881DIL; DIL08
U3B: LM1881SO; SO08
U4: MAX4390; SOT23-5L

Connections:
5V0_FILT: C15.1, C16.2, R2.2, R4.2, U3A.8 (VCC), U3B.8 (VCC), U4.5 (VCC); also elsewhere on the board
COMP_SYNC: U3A.1 (COMP_SYNC), U3B.1 (COMP_SYNC); also elsewhere on the board
GND: FB1.2; also elsewhere on the board
LP_HIT_FROM_PEN: J3.2, R4.1, R5.2; also elsewhere on the board
LP_HIT_TO_CMI: J4.2; also elsewhere on the board
LP_TOUCH_FROM_PEN: J3.5, R2.1, R3.2; also elsewhere on the board
LP_TOUCH_TO_CMI: J4.5; also elsewhere on the board
unnamed: J3.4, J4.4
unnamed: C11.2, U3A.2 (VID_IN), U3B.2 (VID_IN)
unnamed: C12.1, R1.2, U3A.6 (RESET), U3B.6 (RESET)
unnamed: R10.2, R11.2, R13.1, U4.1 (OUT)
unnamed: J8.PIN, R11.1
unnamed: R13.2, R14.1, U4.4 (-IN)
unnamed: R15.1, U4.3 (+IN)
VDU_VIDEO: J1.7, J3.7, R10.1
VIDEO: C11.1, J2.7, J4.7, R15.2, R17.1
VIDEO_GND: C12.2, C15.2, C16.1, FB1.1, J1.8, J2.8, J3.1, J3.3, J3.6, J3.8, J3.9, J3.10, J4.1, J4.3, J4.6, J4.8, J4.9, J4.10, J8.SHLD, R1.1, R3.1, R5.1, R14.2, R17.2, U3A.4 (GND), U3B.4 (GND), U4.2 (GND); also elsewhere on the board
VSYNC: U3A.3 (VSYNC), U3B.3 (VSYNC); also elsewhere on the board

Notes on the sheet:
VDU
Q045 (unused on IIX)
STUFF *ONE*
VIDEO SYNC
SEPARATOR
CMI CONNECTORS
PUP/DN termination, same as
on Q219
Copyright Joe Britt, 2010 - 2017
britt@shapetable.com
Video only, as on Q209 S0 (Series IIX) Q045 S01 (Series II)
Video and LP on IIX: Q209 S0 LP only on II: Q148 S01
FROM
LIGHTPEN
Q219 or Q128
VIDEO SPLITTER / AMP
Gen1 lacked this. With this amp, we can drive 2 monitors simultaneously (CMI VDU and composite monitor)
This opamp can drive two 150 Ohm loads

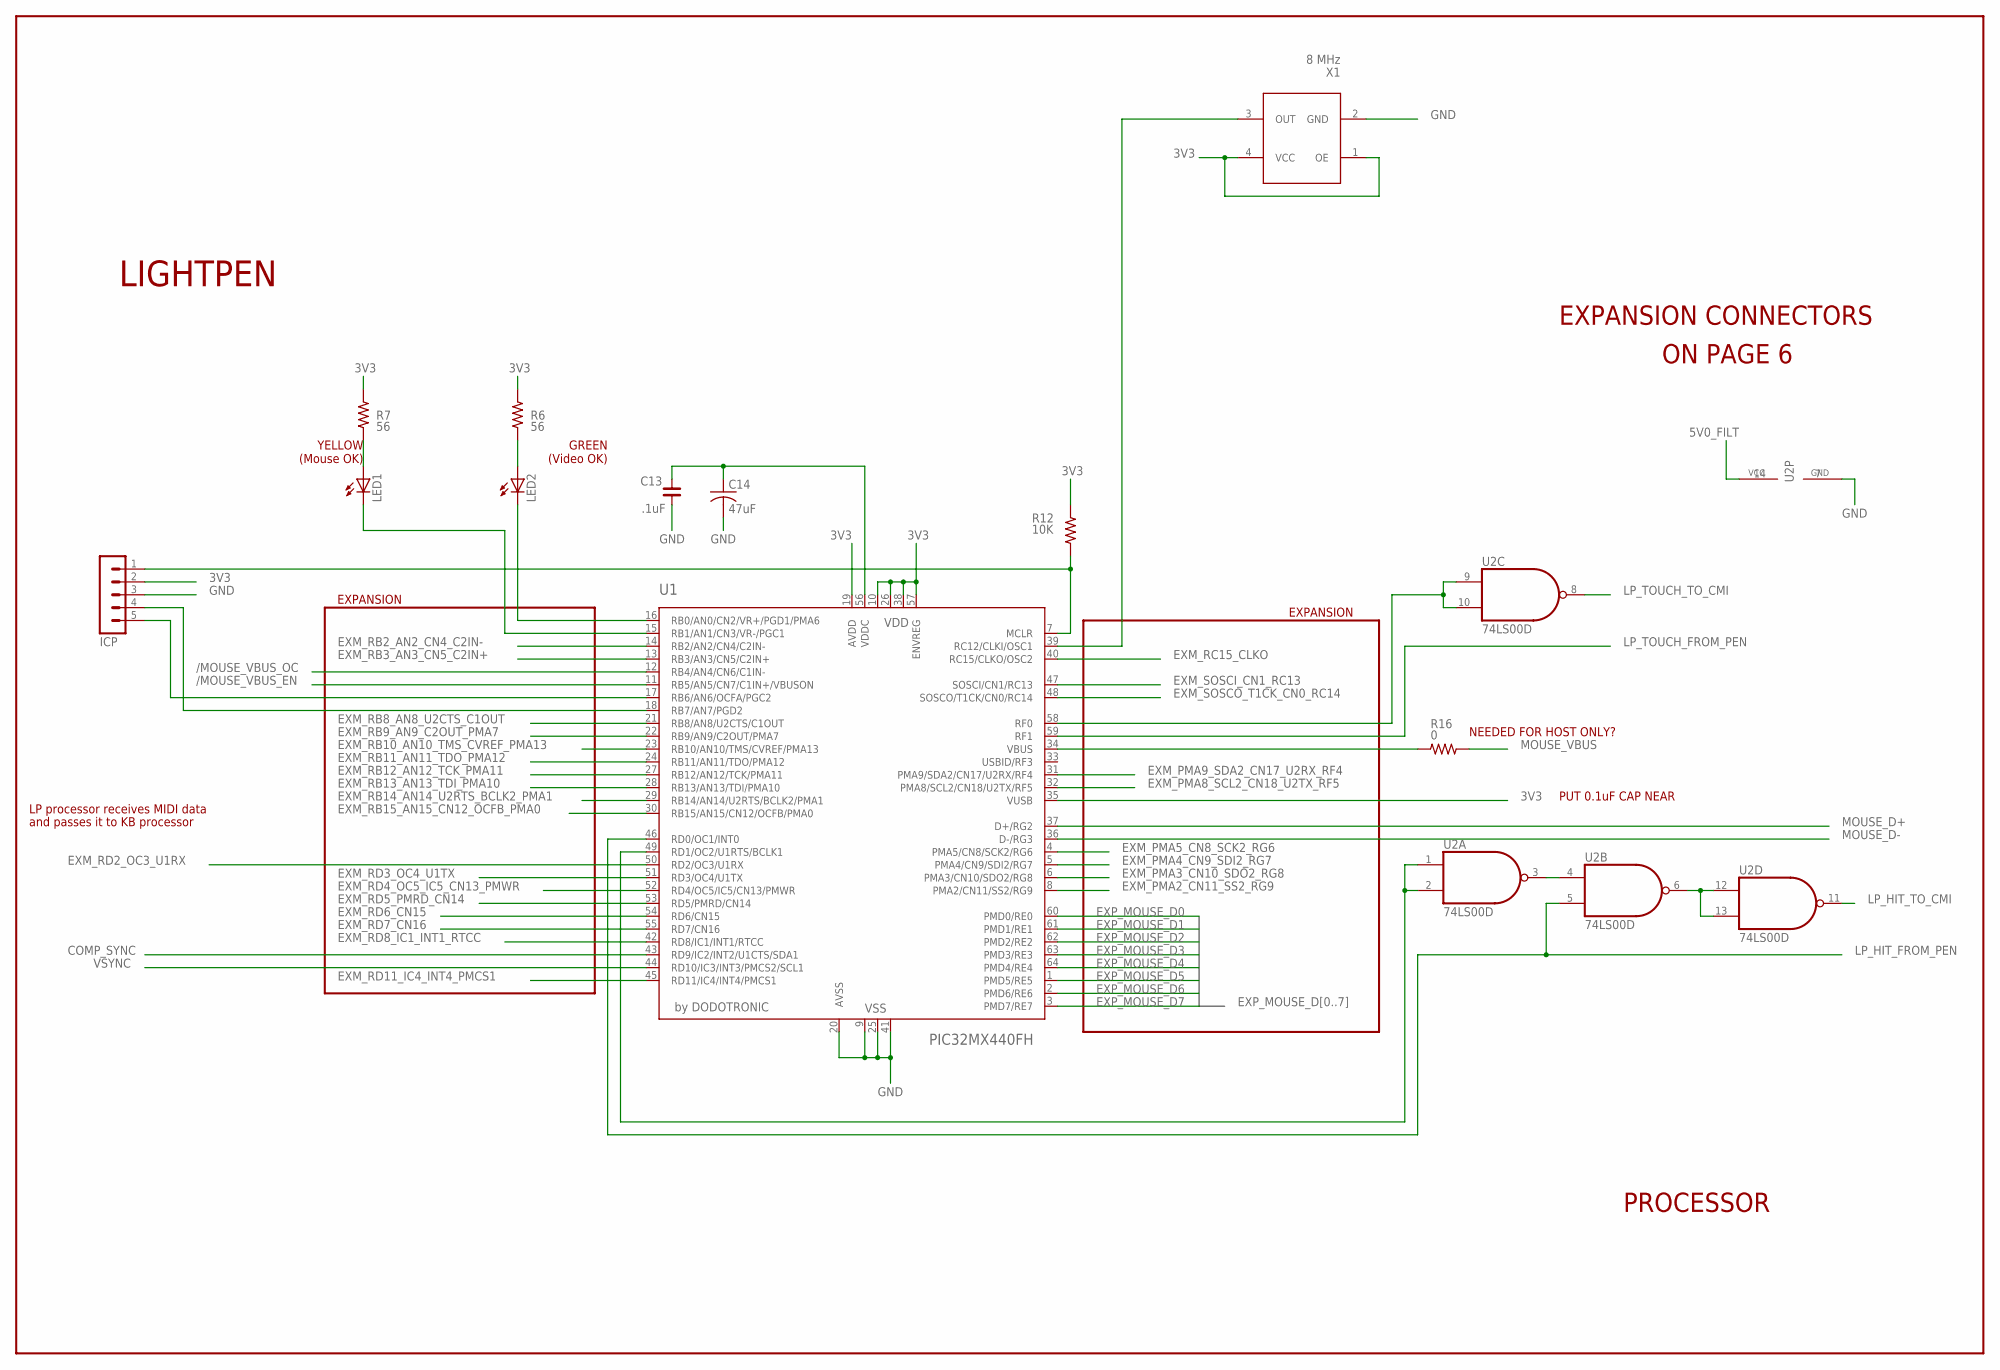
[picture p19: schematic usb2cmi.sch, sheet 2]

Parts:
C13: .1uF; C0603
C14: 47uF; C0805
ICP: MA05-1
LED1, LED2: LEDCHIPLED_0805; CHIPLED_0805
R6, R7: 56; R0603
R12: 10K; R0603
R16: 0; R0603
U1: PIC32MX440FH; TQFP64-10X10
U2: 74LS00D; SO14
X1: 8 MHz; CTS-OSC

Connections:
3V3: ICP.2, R6.2, R7.2, R12.2, U1.10 (VDD), U1.19 (AVDD), U1.26 (VDD), U1.35 (VUSB), U1.38 (VDD), U1.57 (ENVREG), X1.1 (OE), X1.4 (VCC); also elsewhere on the board
5V0_FILT: U2.14 (VCC); also elsewhere on the board
/MOUSE_VBUS_EN: U1.11 (RB5/AN5/CN7/C1IN+/VBUSON); also elsewhere on the board
/MOUSE_VBUS_OC: U1.12 (RB4/AN4/CN6/C1IN-); also elsewhere on the board
COMP_SYNC: U1.43 (RD9/IC2/INT2/U1CTS/SDA1); also elsewhere on the board
EXM_PMA2_CN11_SS2_RG9: U1.8 (PMA2/CN11/SS2/RG9)
EXM_PMA3_CN10_SDO2_RG8: U1.6 (PMA3/CN10/SDO2/RG8)
EXM_PMA4_CN9_SDI2_RG7: U1.5 (PMA4/CN9/SDI2/RG7)
EXM_PMA5_CN8_SCK2_RG6: U1.4 (PMA5/CN8/SCK2/RG6)
EXM_PMA8_SCL2_CN18_U2TX_RF5: U1.32 (PMA8/SCL2/CN18/U2TX/RF5); also elsewhere on the board
EXM_PMA9_SDA2_CN17_U2RX_RF4: U1.31 (PMA9/SDA2/CN17/U2RX/RF4); also elsewhere on the board
EXM_RB0_AN0_CN2_PMA6: LED2.C, U1.16 (RB0/AN0/CN2/VR+/PGD1/PMA6)
EXM_RB2_AN2_CN4_C2IN-: U1.14 (RB2/AN2/CN4/C2IN-)
EXM_RB3_AN3_CN5_C2IN+: U1.13 (RB3/AN3/CN5/C2IN+)
EXM_RB8_AN8_U2CTS_C1OUT: U1.21 (RB8/AN8/U2CTS/C1OUT)
EXM_RB9_AN9_C2OUT_PMA7: U1.22 (RB9/AN9/C2OUT/PMA7)
EXM_RB10_AN10_TMS_CVREF_PMA13: U1.23 (RB10/AN10/TMS/CVREF/PMA13)
EXM_RB11_AN11_TDO_PMA12: U1.24 (RB11/AN11/TDO/PMA12)
EXM_RB12_AN12_TCK_PMA11: U1.27 (RB12/AN12/TCK/PMA11)
EXM_RB13_AN13_TDI_PMA10: U1.28 (RB13/AN13/TDI/PMA10)
EXM_RB14_AN14_U2RTS_BCLK2_PMA1: U1.29 (RB14/AN14/U2RTS/BCLK2/PMA1)
EXM_RB15_AN15_CN12_OCFB_PMA0: U1.30 (RB15/AN15/CN12/OCFB/PMA0)
EXM_RC15_CLKO: U1.40 (RC15/CLKO/OSC2)
EXM_RD2_OC3_U1RX: U1.50 (RD2/OC3/U1RX); also elsewhere on the board
EXM_RD3_OC4_U1TX: U1.51 (RD3/OC4/U1TX); also elsewhere on the board
EXM_RD4_OC5_IC5_CN13_PMWR: U1.52 (RD4/OC5/IC5/CN13/PMWR)
EXM_RD5_PMRD_CN14: U1.53 (RD5/PMRD/CN14)
EXM_RD6_CN15: U1.54 (RD6/CN15)
EXM_RD7_CN16: U1.55 (RD7/CN16)
EXM_RD8_IC1_INT1_RTCC: U1.42 (RD8/IC1/INT1/RTCC)
EXM_RD11_IC4_INT4_PMCS1: U1.45 (RD11/IC4/INT4/PMCS1)
EXM_SOSCI_CN1_RC13: U1.47 (SOSCI/CN1/RC13)
EXM_SOSCO_T1CK_CN0_RC14: U1.48 (SOSCO/T1CK/CN0/RC14)
EXP_MOUSE_D0: U1.60 (PMD0/RE0)
EXP_MOUSE_D1: U1.61 (PMD1/RE1)
EXP_MOUSE_D2: U1.62 (PMD2/RE2)
EXP_MOUSE_D3: U1.63 (PMD3/RE3)
EXP_MOUSE_D4: U1.64 (PMD4/RE4)
EXP_MOUSE_D5: U1.1 (PMD5/RE5)
EXP_MOUSE_D6: U1.2 (PMD6/RE6)
EXP_MOUSE_D7: U1.3 (PMD7/RE7)
GND: C13.2, C14.2, ICP.3, U1.9 (VSS), U1.20 (AVSS), U1.25 (VSS), U1.41 (VSS), U2.7 (GND), X1.2 (GND); also elsewhere on the board
LP_HIT_FROM_PEN: U1.46 (RD0/OC1/INT0), U2.5 (I1); also elsewhere on the board
LP_HIT_TO_CMI: U2.11 (O); also elsewhere on the board
LP_TOUCH_FROM_PEN: U1.59 (RF1); also elsewhere on the board
LP_TOUCH_TO_CMI: U2.8 (O); also elsewhere on the board
MOUSE_D+: U1.37 (D+/RG2); also elsewhere on the board
MOUSE_D-: U1.36 (D-/RG3); also elsewhere on the board
MOUSE_VBUS: R16.1; also elsewhere on the board
unnamed: C13.1, C14.1, U1.56 (VDDC)
unnamed: LED2.A, R6.1
unnamed: LED1.C, U1.15 (RB1/AN1/CN3/VR-/PGC1)
unnamed: U1.39 (RC12/CLKI/OSC1), X1.3 (OUT)
unnamed: U1.58 (RF0), U2.9 (I0), U2.10 (I1)
unnamed: U2.6 (O), U2.12 (I0), U2.13 (I1)
unnamed: U2.3 (O), U2.4 (I0)
unnamed: U1.49 (RD1/OC2/U1RTS/BCLK1), U2.1 (I0), U2.2 (I1)
unnamed: LED1.A, R7.1
unnamed: R16.2, U1.34 (VBUS)
PGC: ICP.5, U1.17 (RB6/AN6/OCFA/PGC2)
PGD: ICP.4, U1.18 (RB7/AN7/PGD2)
U2_MCLR: ICP.1, R12.1, U1.7 (MCLR)
VSYNC: U1.44 (RD10/IC3/INT3/PMCS2/SCL1); also elsewhere on the board

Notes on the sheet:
LIGHTPEN
YELLOW (Mouse OK)
NEEDED FOR HOST ONLY?
PUT 0.1uF CAP NEAR
EXPANSION CONNECTORS
ON PAGE 6
PROCESSOR
EXPANSION
LP processor receives MIDI data
and passes it to KB processor
GREEN (Video OK)

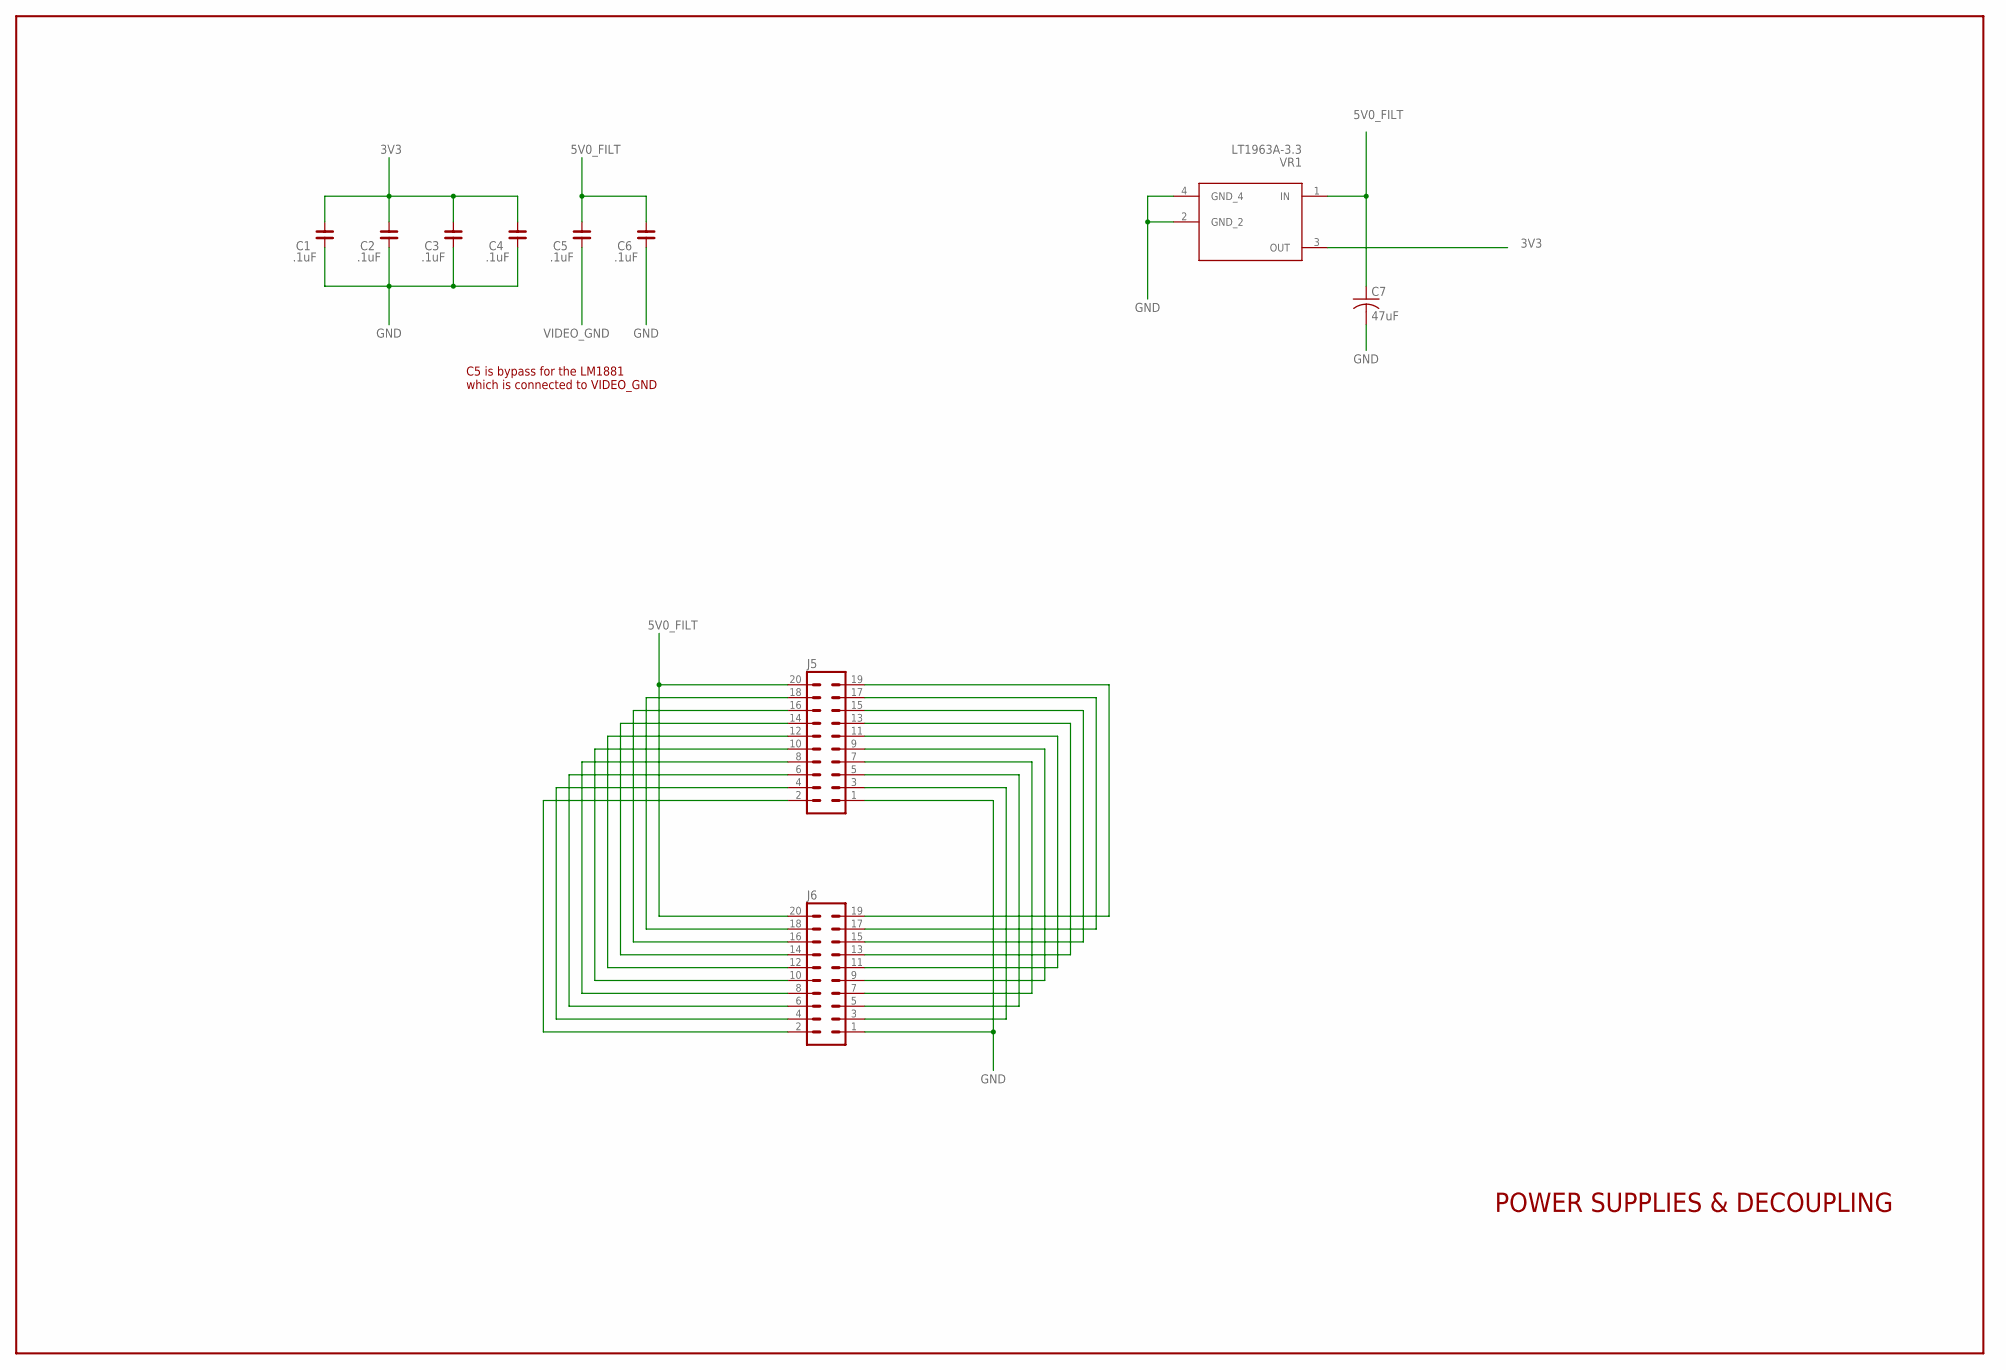
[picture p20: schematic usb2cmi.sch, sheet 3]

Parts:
C1, C2, C3, C4, C5, C6: .1uF; C0603
C7: 47uF; C0805
J5: 20H
J6: ML20
VR1: LT1963A-3.3; SOT-223

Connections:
3V3: C1.1, C2.1, C3.1, C4.1, VR1.3 (OUT); also elsewhere on the board
5V0_FILT: C5.1, C6.1, C7.1, J5.20, J6.20, VR1.1 (IN); also elsewhere on the board
GND: C1.2, C2.2, C3.2, C4.2, C6.2, C7.2, J5.1, J6.1, VR1.2 (GND_2), VR1.4 (GND_4); also elsewhere on the board
unnamed: J5.18, J6.18
unnamed: J5.16, J6.16
unnamed: J5.14, J6.14
unnamed: J5.12, J6.12
unnamed: J5.10, J6.10
unnamed: J5.8, J6.8
unnamed: J5.6, J6.6
unnamed: J5.4, J6.4
unnamed: J5.2, J6.2
unnamed: J5.3, J6.3
unnamed: J5.5, J6.5
unnamed: J5.7, J6.7
unnamed: J5.9, J6.9
unnamed: J5.11, J6.11
unnamed: J5.13, J6.13
unnamed: J5.15, J6.15
unnamed: J5.17, J6.17
unnamed: J5.19, J6.19
VIDEO_GND: C5.2; also elsewhere on the board

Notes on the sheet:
POWER SUPPLIES & DECOUPLING
C5 is bypass for the LM1881 which is connected to VIDEO_GND

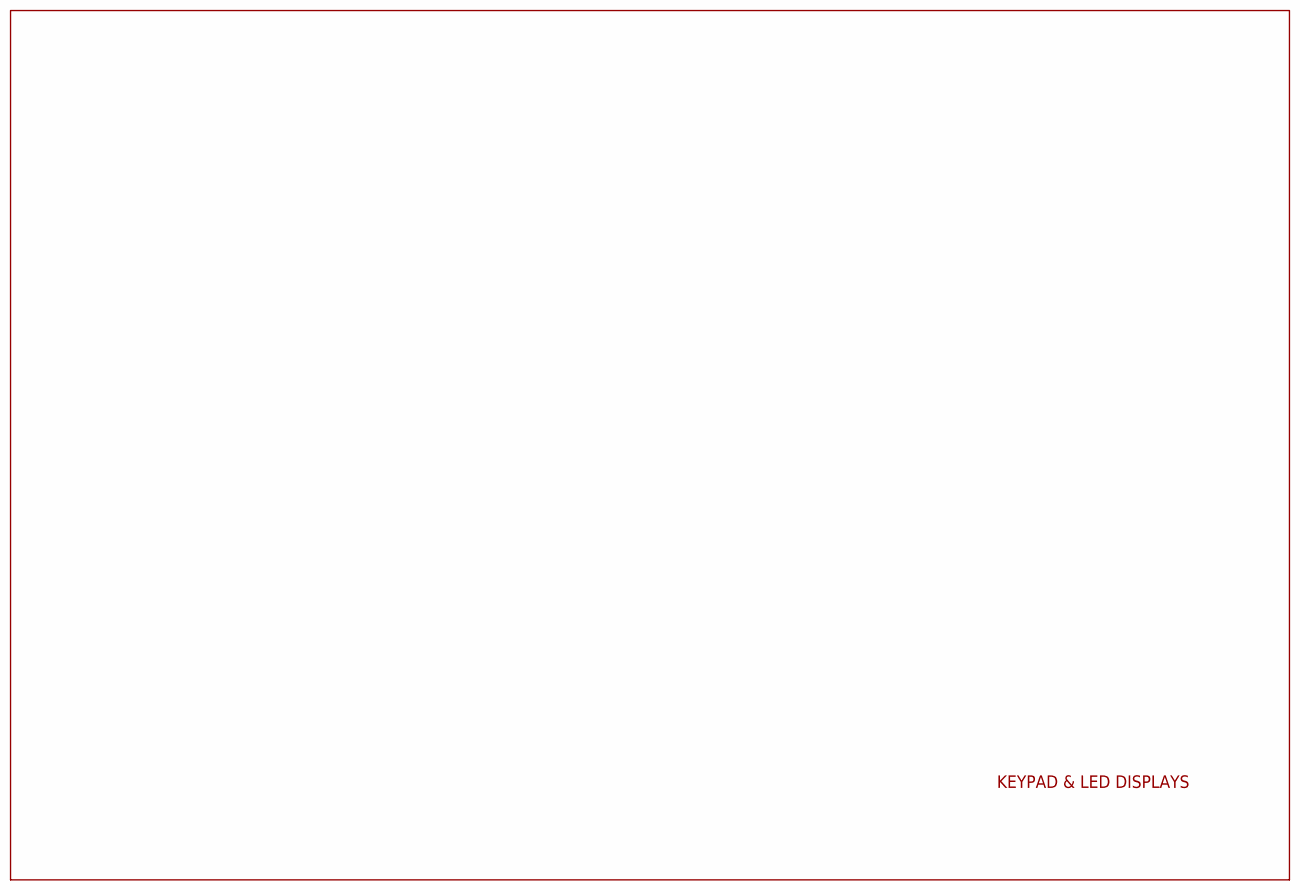
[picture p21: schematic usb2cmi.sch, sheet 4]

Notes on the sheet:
KEYPAD & LED DISPLAYS

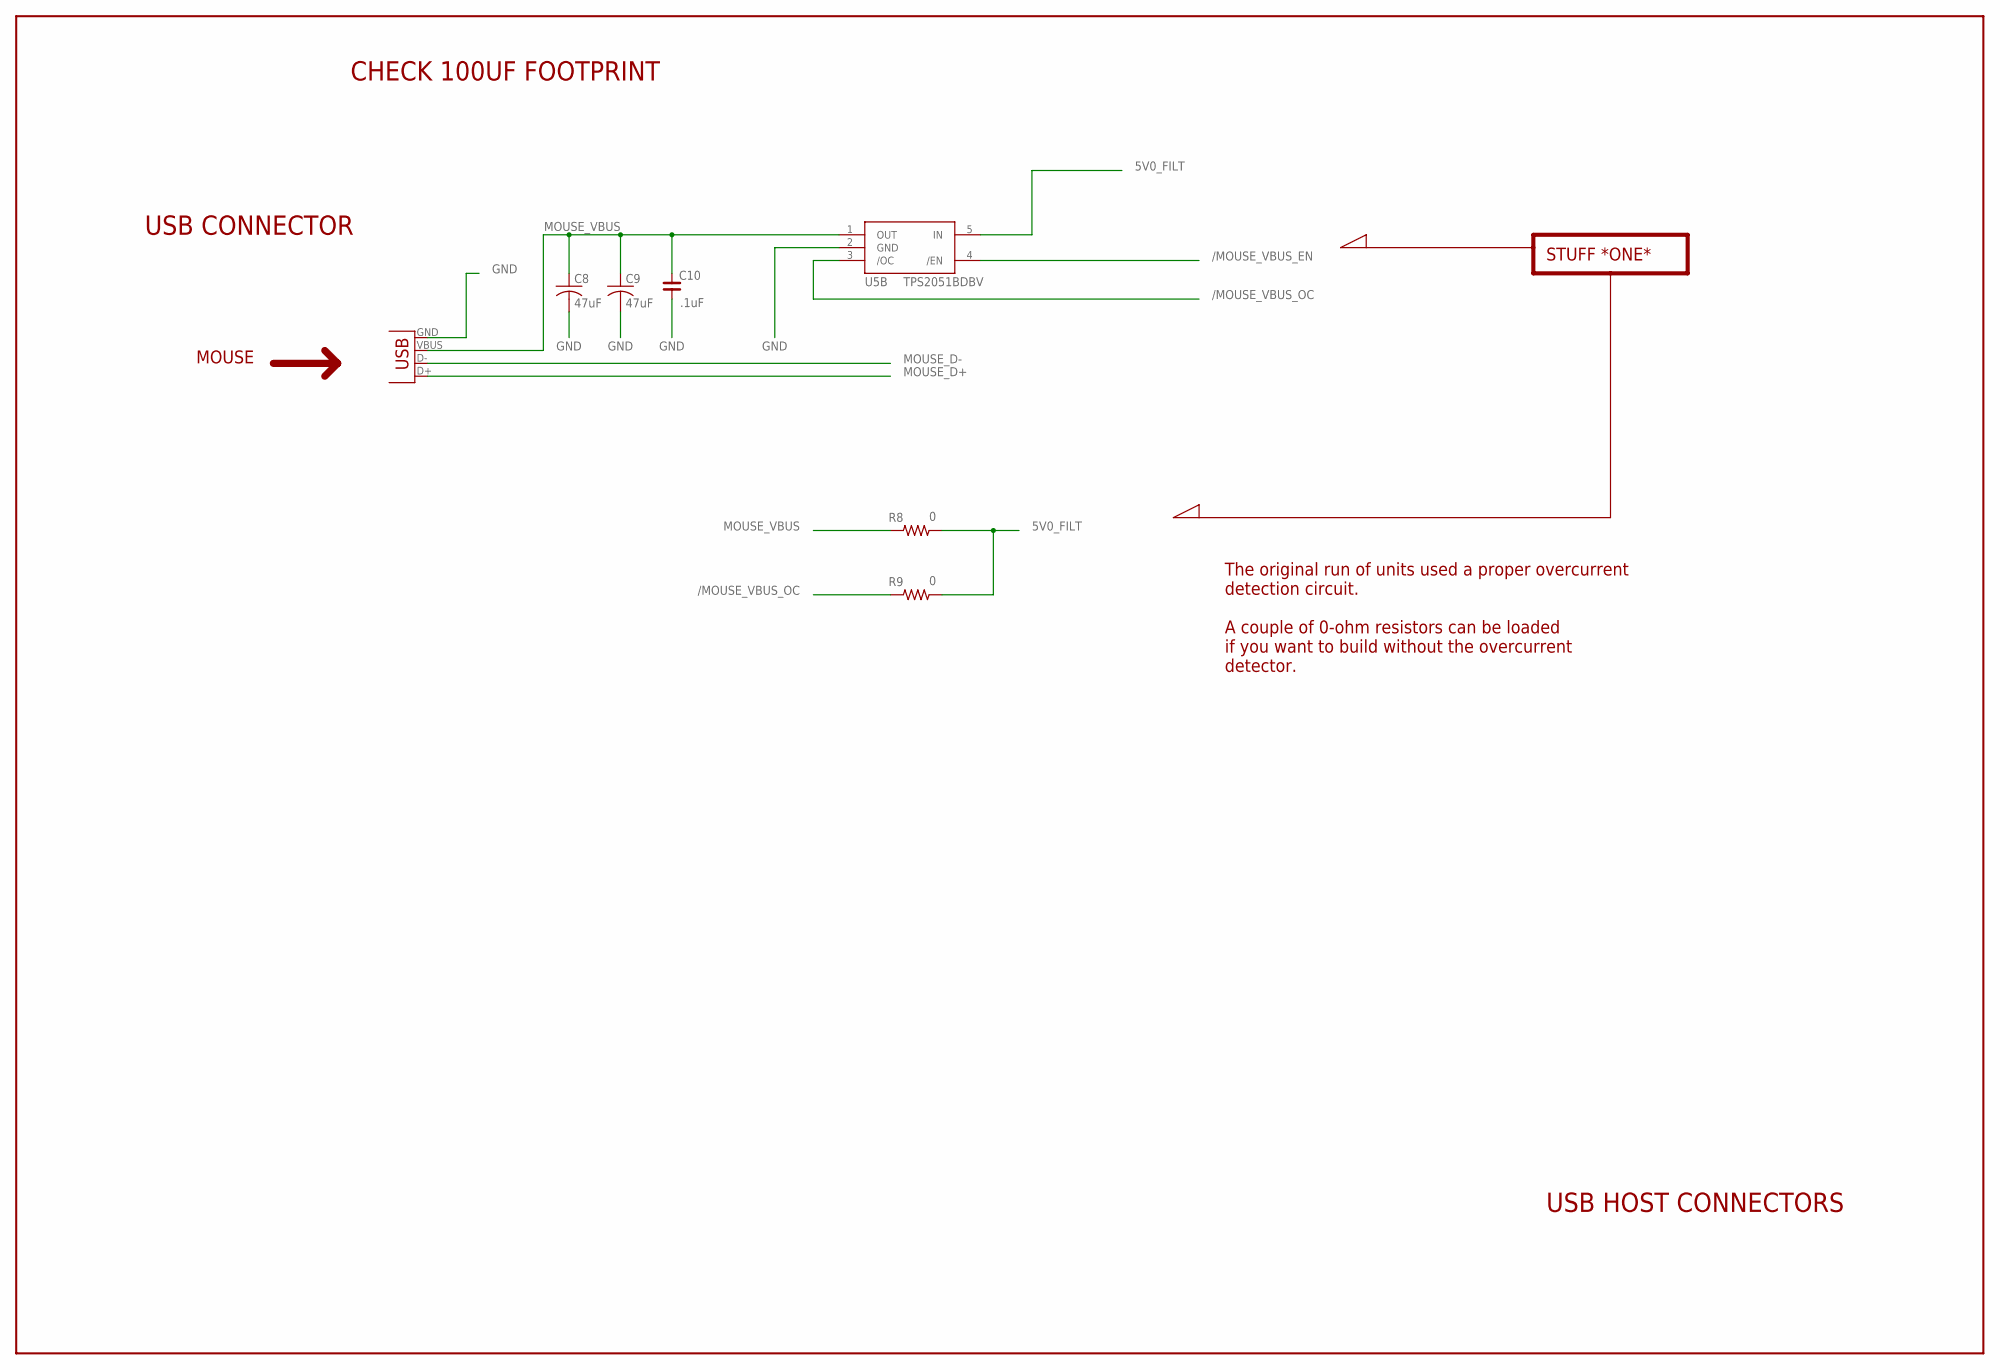
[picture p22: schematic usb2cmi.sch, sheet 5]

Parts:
C8, C9: 47uF; C0805
C10: .1uF; C0603
J7: USB-A-H
R8, R9: 0; R0603
U5B: TPS2051BDBV; DBV-5

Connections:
5V0_FILT: R8.1, R9.1, U5B.5 (IN); also elsewhere on the board
/MOUSE_VBUS_EN: U5B.4 (/EN); also elsewhere on the board
/MOUSE_VBUS_OC: R9.2, U5B.3 (/OC); also elsewhere on the board
GND: C8.2, C9.2, C10.2, J7.GND, U5B.2 (GND); also elsewhere on the board
MOUSE_D+: J7.D+; also elsewhere on the board
MOUSE_D-: J7.D-; also elsewhere on the board
MOUSE_VBUS: C8.1, C9.1, C10.1, J7.VBUS, R8.2, U5B.1 (OUT); also elsewhere on the board

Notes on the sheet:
MOUSE
USB CONNECTOR
STUFF *ONE*
CHECK 100UF FOOTPRINT
USB HOST CONNECTORS
The original run of units used a proper overcurrent detection circuit. A couple of 0-ohm resistors can be loaded if you want to build without the overcurrent detector.

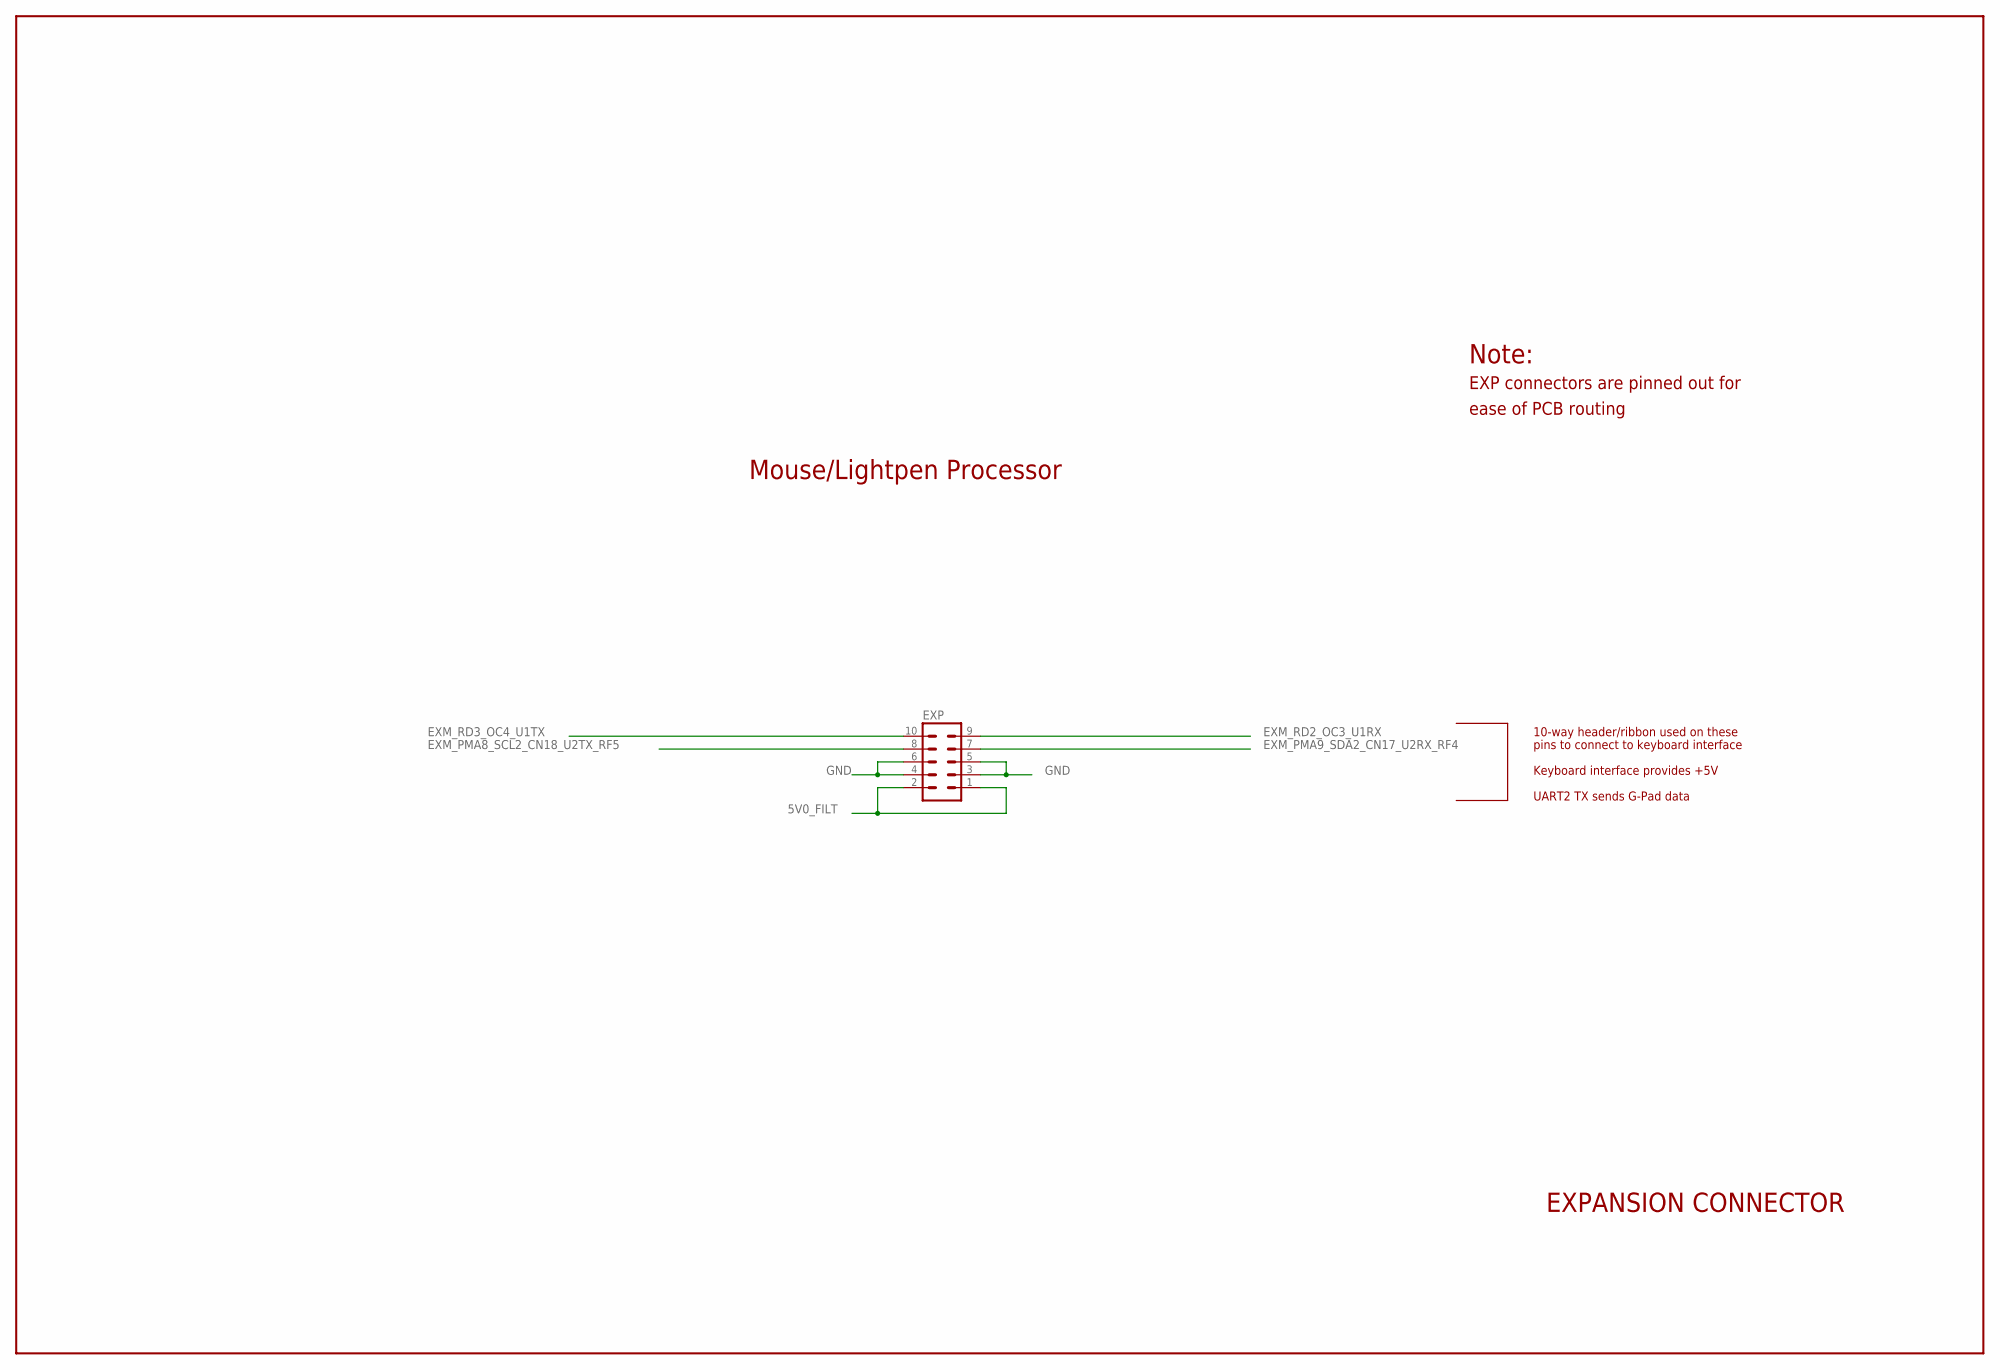
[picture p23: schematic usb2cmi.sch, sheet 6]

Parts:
EXP: MA05-2

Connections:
5V0_FILT: EXP.1, EXP.2; also elsewhere on the board
EXM_PMA8_SCL2_CN18_U2TX_RF5: EXP.8; also elsewhere on the board
EXM_PMA9_SDA2_CN17_U2RX_RF4: EXP.7; also elsewhere on the board
EXM_RD2_OC3_U1RX: EXP.9; also elsewhere on the board
EXM_RD3_OC4_U1TX: EXP.10; also elsewhere on the board
GND: EXP.3, EXP.4, EXP.5, EXP.6; also elsewhere on the board

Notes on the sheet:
Mouse/Lightpen Processor
EXPANSION CONNECTOR
Note:
EXP connectors are pinned out for
ease of PCB routing
10-way header/ribbon used on these
pins to connect to keyboard interface
Keyboard interface provides +5V
UART2 TX sends G-Pad data

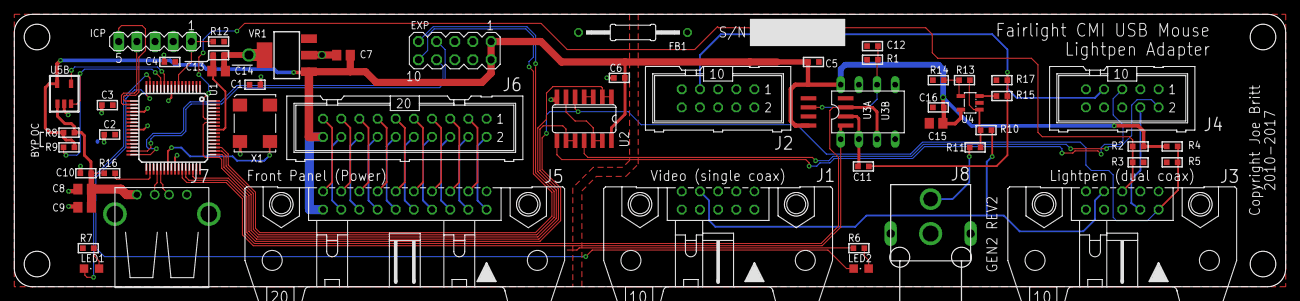
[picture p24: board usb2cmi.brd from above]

Board: 2 copper layers, 177.8 x 38.1 mm, 54 parts (0 on the bottom side), 60 nets.

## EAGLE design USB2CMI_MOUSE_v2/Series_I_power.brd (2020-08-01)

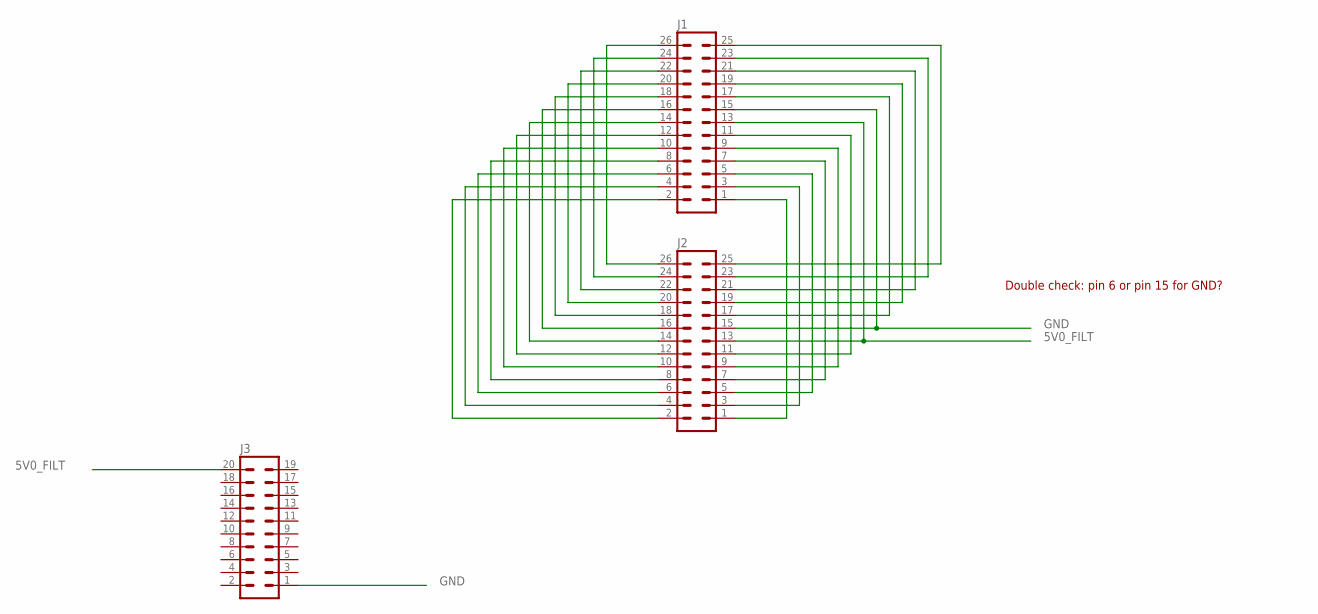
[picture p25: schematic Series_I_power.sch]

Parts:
J1, J2: 26H
J3: ML20

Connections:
5V0_FILT: J1.13, J2.13, J3.20
GND: J1.15, J2.15, J3.1
unnamed: J1.26, J2.26
unnamed: J1.24, J2.24
unnamed: J1.22, J2.22
unnamed: J1.20, J2.20
unnamed: J1.18, J2.18
unnamed: J1.16, J2.16
unnamed: J1.14, J2.14
unnamed: J1.12, J2.12
unnamed: J1.10, J2.10
unnamed: J1.8, J2.8
unnamed: J1.6, J2.6
unnamed: J1.4, J2.4
unnamed: J1.2, J2.2
unnamed: J1.1, J2.1
unnamed: J1.3, J2.3
unnamed: J1.5, J2.5
unnamed: J1.7, J2.7
unnamed: J1.9, J2.9
unnamed: J1.11, J2.11
unnamed: J1.17, J2.17
unnamed: J1.19, J2.19
unnamed: J1.21, J2.21
unnamed: J1.23, J2.23
unnamed: J1.25, J2.25

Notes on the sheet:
Double check: pin 6 or pin 15 for GND?

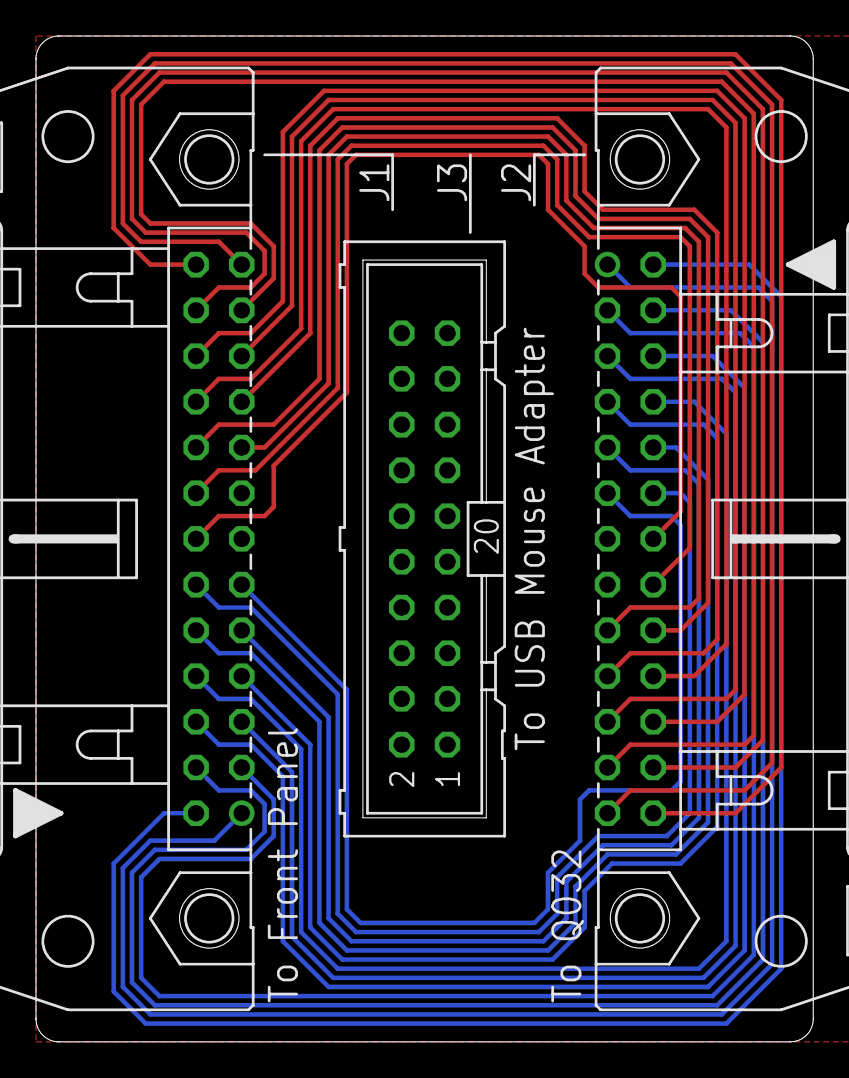
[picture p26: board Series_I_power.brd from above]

Board: 2 copper layers, 43.2 x 55.9 mm, 3 parts (0 on the bottom side), 26 nets.

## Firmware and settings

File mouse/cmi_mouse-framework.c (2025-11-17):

/******************************************************************************
	Framework derived from Microchip sample code Mouse_demo.c.

	Lightpen emulation code Copyright 2010 Joe Britt (britt@shapetable.com).
	All rights reserved.  Released under the 2-clause BSD license:

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
	1. Redistributions of source code must retain the above copyright notice, this list of
      conditions and the following disclaimer.

	2. Redistributions in binary form must reproduce the above copyright notice, this list
      of conditions and the following disclaimer in the documentation and/or other materials
      provided with the distribution.

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
	The views and conclusions contained in the software and documentation are those of the
	authors and should not be interpreted as representing official policies, either expressed
	or implied, of Joe Britt.

	----------------------------------------------------------------------------
	Original Microchip header below:

    Any Low speed/Full Speed USB Mouse can be connected. 
	This file schedules the HID ransfers, and interprets the report received from the mouse.
	X & Y axis coordinates, Left & Right Click received from the mouse are available.

	* File Name:       Mouse_demo.c
	* Company:         Microchip Technology, Inc.

	Software License Agreement

	The software supplied herewith by Microchip Technology Incorporated
	(the “Company”) for its PICmicro® Microcontroller is intended and
	supplied to you, the Company’s customer, for use solely and
	exclusively on Microchip PICmicro Microcontroller products. The
	software is owned by the Company and/or its supplier, and is
	protected under applicable copyright laws. All rights are reserved.
	Any use in violation of the foregoing restrictions may subject the
	user to criminal sanctions under applicable laws, as well as to
	civil liability for the breach of the terms and conditions of this
	license.

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
	Version          Date    Comments
	--------------------------------------------------------------------------------
	?            14-Apr-2008 First release

*******************************************************************************/

#include <stdlib.h>
#include <string.h>
#include <stdio.h>

#include "GenericTypeDefs.h"
#include "HardwareProfile.h"

#include "usb_config.h"

#include "usb/usb.h"
#include "usb/usb_host_hid_parser.h"
#include "usb/usb_host_hid.h"

#include <plib.h>

#include "pos_II.h"
#include "pos_IIx.h"

/*
	This is used to tweak the offsets when tuning the pixel offset tables
	to minimize cursor jitter.

	Note that for machines which use the Q045 video board (Series I/II), the analog
	adjustments for active screen area position & width make automatic de-jittering
	difficult.

	You can use the RV1 and RV2 pots on that board to adjust the video to minimize
	jitter.
*/
//#define	TUNE_TIMING		1

// *****************************************************************************
// Configuration Bits
// *****************************************************************************

#if defined( __PIC32MX__ )
    #pragma config UPLLEN   = ON            // USB PLL Enabled
    #pragma config FPLLMUL  = MUL_20        // PLL Multiplier
    #pragma config UPLLIDIV = DIV_2         // USB PLL Input Divider
    #pragma config FPLLIDIV = DIV_2         // PLL Input Divider
    #pragma config FPLLODIV = DIV_1         // PLL Output Divider
    #pragma config FPBDIV   = DIV_1         // Peripheral Clock divisor
    #pragma config FWDTEN   = OFF           // Watchdog Timer
    #pragma config WDTPS    = PS1           // Watchdog Timer Postscale
    #pragma config FCKSM    = CSDCMD        // Clock Switching & Fail Safe Clock Monitor
    #pragma config OSCIOFNC = OFF           // CLKO Enable
    #pragma config POSCMOD  = EC            // Primary Oscillator, External Clock
    #pragma config IESO     = OFF           // Internal/External Switch-over
    #pragma config FSOSCEN  = OFF           // Secondary Oscillator Enable (KLO was off)
    #pragma config FNOSC    = PRIPLL        // Oscillator Selection
    #pragma config CP       = OFF           // Code Protect
    #pragma config BWP      = OFF           // Boot Flash Write Protect
    #pragma config PWP      = OFF           // Program Flash Write Protect
    #pragma config ICESEL   = ICS_PGx2      // ICE/ICD Comm Channel Select
    #pragma config DEBUG    = ON			// Debugger Disabled for Starter Kit
#else
    #error Cannot define configuration bits.
#endif

// *****************************************************************************
// USB Data Structures
// *****************************************************************************

typedef enum _APP_STATE
{
    DEVICE_NOT_CONNECTED,
    DEVICE_CONNECTED,		/* Device Enumerated  - Report Descriptor Parsed */
    READY_TO_TX_RX_REPORT,
    GET_INPUT_REPORT,		/* perform operation on received report */
    INPUT_REPORT_PENDING,
    ERROR_REPORTED 
} APP_STATE;

typedef struct _HID_REPORT_BUFFER
{
    WORD  Report_ID;
    WORD  ReportSize;
    BYTE  ReportData[4];	// BYTE* ReportData;
    WORD  ReportPollRate;
}   HID_REPORT_BUFFER;

// *****************************************************************************
// USB Internal Function Prototypes
// *****************************************************************************

void AppInitialize(void);
BOOL AppGetParsedReportDetails(void);
void App_Detect_Device(void);
void App_ProcessInputReport(void);
BOOL USB_HID_DataCollectionHandler(void);

// *****************************************************************************
// USB Constants
// *****************************************************************************
#define MAX_ALLOWED_CURRENT             (500)         // Maximum power we can supply in mA
//#define MINIMUM_POLL_INTERVAL           (0x0A)        // Minimum Polling rate for HID reports is 10ms

#define USAGE_PAGE_BUTTONS              (0x09)

#define USAGE_PAGE_GEN_DESKTOP          (0x01)

#define MAX_ERROR_COUNTER               (10)

// *****************************************************************************
// General USB global Variables
// *****************************************************************************

APP_STATE App_State_Mouse = DEVICE_NOT_CONNECTED;

HID_DATA_DETAILS Appl_Mouse_Buttons_Details;
HID_DATA_DETAILS Appl_XY_Axis_Details;

HID_REPORT_BUFFER  Appl_raw_report_buffer;

// need safety margin?  these were 3, and other memory was getting stomped
HID_USER_DATA_SIZE Appl_Button_report_buffer[16];
HID_USER_DATA_SIZE Appl_XY_report_buffer[16];

BYTE ErrorDriver;
BYTE ErrorCounter;
BYTE NumOfBytesRcvd;

BOOL ReportBufferUpdated;

// *****************************************************************************
// Lightpen emulation global Variables
// *****************************************************************************

SHORT			xpos;					//	lightpen cursor position
SHORT			ypos;

unsigned int	y_bias;					// scanlines to active video (different for I/II vs. IIx)

SHORT			xpos_jitter;			// wiggle xpos this many pixels when button is down (TOUCH)

SHORT			gpad_x;					// G-Pad (Series III) cursor position
SHORT			gpad_y;

unsigned int	lastVSYNC;				// count captured at last VSYNC
unsigned int	lastStat;

unsigned int	*pos_tbl;				// pixel -> clock offset table
unsigned int	pos;					// xpos converted to TMR23 count

unsigned int	show_cursor;
unsigned int	show_cursor_gpad;

unsigned int	lineCount;
unsigned int	cursorLine;
unsigned int	drawnLines;

unsigned int	mouse_left_button;		// non-zero when left button down

unsigned int	blinker;				// used to blink the green LED when no video present

unsigned int	real_hit_count_now;		// counts HIT pulses from real LP
unsigned int	real_hit_count_last;	// pulse count at last vsync

//******************************************************************************
// USB Support Functions
//******************************************************************************

BOOL USB_ApplicationEventHandler( BYTE address, USB_EVENT event, void *data, DWORD size )
{
    switch( event )
    {
        case EVENT_VBUS_REQUEST_POWER:
            // The data pointer points to a byte that represents the amount of power
            // requested in mA, divided by two.  If the device wants too much power,
            // we reject it.
            if (((USB_VBUS_POWER_EVENT_DATA*)data)->current <= (MAX_ALLOWED_CURRENT / 2))
            {
                return TRUE;
            }
            else
            {
                //UART2PrintString( "\r\n***** USB Error - device requires too much current *****\r\n" );
            }
            break;

        case EVENT_VBUS_RELEASE_POWER:
            // Turn off Vbus power.
            return TRUE;
            break;

        case EVENT_HUB_ATTACH:
            //UART2PrintString( "\r\n***** USB Error - hubs are not supported *****\r\n" );
            return TRUE;
            break;

        case EVENT_UNSUPPORTED_DEVICE:
            //UART2PrintString( "\r\n***** USB Error - device is not supported *****\r\n" );
            return TRUE;
            break;

        case EVENT_CANNOT_ENUMERATE:
            //UART2PrintString( "\r\n***** USB Error - cannot enumerate device *****\r\n" );
            return TRUE;
            break;

        case EVENT_CLIENT_INIT_ERROR:
            //UART2PrintString( "\r\n***** USB Error - client driver initialization error *****\r\n" );
            return TRUE;
            break;

        case EVENT_OUT_OF_MEMORY:
            //UART2PrintString( "\r\n***** USB Error - out of heap memory *****\r\n" );
            return TRUE;
            break;

        case EVENT_UNSPECIFIED_ERROR:   // This should never be generated.
            //UART2PrintString( "\r\n***** USB Error - unspecified *****\r\n" );
            return TRUE;
            break;

		case EVENT_HID_RPT_DESC_PARSED:
			 #ifdef APPL_COLLECT_PARSED_DATA
			     return(APPL_COLLECT_PARSED_DATA());
		     #else
				 return TRUE;
			 #endif
			break;

        default:
            break;
    }
    return FALSE;
}


/*
LIGHT PEN EMULATION

Q219 Video Basics
-----------------
The active video is 512 pixels wide and 256 pixels tall.  From the service manual, 
the actual video signal is 84 bytes/line (672 dot clocks) and 304 lines, so a full 
frame is 672 dot clks/line * 304 lines = 204,288 dot clocks.

Each HSYNC starts at the 68th byte position on a line and lasts for 6 byte times 
(so 48 dot clocks).

Since there are 84 bytes/line, that means:
64 bytes of pixels + 6 bytes of HSYNC + 14 bytes of nothing.

Each VSYNC starts on line 272 and lasts for 4 lines, or 672 * 4 = 2688 dot clocks = 259 uS.

Since there are 304 lines, that means:
256 lines of pixels + 4 lines of VSYNC + 44 lines of nothing.

Lightpen Basics
---------------
There are 2 active-low TTL signals from the LP: HIT goes low when the photodetector 
sees the beam go past, and TOUCH goes low when the user touches the end of the pen 
with his/her finger.

Q219 deglitches the HIT signal by requiring that the 2 scanlines after an initial 
HIT also generate a HIT.  That generates LPSTB which latches the counters and 
generates an interrupt.  Interrupt handler reads counters to get LP position.

TOUCH is just like a mouse button.

Mouse -> Lightpen Emulation
---------------------------
There is a Virtual Light Pen (VLP) coordinate with X,Y (xpos, ypos variables) expressed
as screen pixels (X = 0->511, Y = 0->255).  These X & Y values are updated when the mouse
moves by the USB host code running on the PIC32.

Mouse movement generates relative movement values.  These are added to the VLP coordinate 
to update the VLP position.  So, the X and Y values always indicate where the cursor
should be "drawn."

An LM1881 Video Sync Separator is fed the video signal from the Q219, and extracts
VSYNC and Composite Sync (CSYNC).  CSYNC is both VSYNC and HSYNC.

We use the PIC32's 32 bit high-speed timer and two Input Capture peripherals to synchronize
with the Q219 video.  We then use one of the PIC32's Output Compare peripherals to generate
pulses on the lightpen HIT line with the right timing to make the Q219 think that the 
lightpen saw the beam fly by.

The PIC32's Timer 2 and 3 are bonded into a 32 bit counter, clocked by the internal 
80MHz clock.

The natural dotclk of the Q219 board is 10.38MHz.  There are then 7.7 80MHz timer ticks per
10.38MHz dot clock.  This is enough resolution to generate HIT pulses within a dotclk
(pixel) window to get a stable cursor on the screen.

When we get a VSYNC interrupt, we clear the line counter -- we're now at the top of the
frame.  We then wait for the VSYNC to end, an know that from this point on the CSYNC
interrupts we get are really HSYNC interrupts.

Each CSYNC/HSYNC interrupt increments our line counter and checks to see if the current
cursor (VLP) position has a scanline on this line.  If it does, the Output Compare is
set up to generate a HIT pulse at the appropriate pixel position and with the appropriate
length.

Note that the Q219 has a feature called a "hit deglitcher."  Because of this, the hotspot
of the cursor is really at the leftmost point of the *second* scanline of the cursor.
(That's why I gave the mouse cursor the shape it has.)

Status LEDs
-----------
There are 2 LEDs on the board:

The Green LED indicates power and video detected, and is normally on solid.  
If there is no video detected, it blinks.
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
int main (void)
{
	SHORT last_gpad_x;		// previous G-Pad (Series III) cursor position
	SHORT last_gpad_y;		//  (used to prevent re-sending same position over & over)
	SHORT last_show_cursor_gpad;
	SHORT last_mouse_left_button;

	int buzz;

	int	value;

	value = SYSTEMConfigWaitStatesAndPB( GetSystemClock() );
    
	// Enable the cache for the best performance
	CheKseg0CacheOn();
    
	INTEnableSystemMultiVectoredInt();
    
	value = OSCCON;
	while (!(value & 0x00000020))
	{
		value = OSCCON;		// Wait for PLL lock to stabilize
	}
        
	AD1PCFG = 0xFFFF;   	// Set analog pins to digital.
	TRISF   = 0x00;
	TRISD   = 0x00C0;

	// UART2 is used to communicate with the Keyboard interface (if installed)

	Init_UART2( 9600 );

	// Init the USB host stack

	USBInitialize( 0 );

	// Init our globals

	xpos = INIT_XPOS;			// initial cursor position
	ypos = INIT_YPOS;

	y_bias = Y_BIAS_IIX;		// assume we're a IIx, interrupt code will select the right
								//  setting based on video timing

#ifdef TUNE_TIMING
	adjust = 0;
	Init_UART1( 9600 );
#endif

	last_gpad_x = gpad_x = (MAX_GPAD_X / 2);
	last_gpad_y = gpad_y = (MAX_GPAD_Y / 2);

	show_cursor = 1;			// cursor on by default

	show_cursor_gpad = 1;		// separate one for G-Pad, since video detector automatically
								//  turns the other one back on
	mouse_left_button = 0;

	real_hit_count_now = real_hit_count_last = 0;

	blinker = 0;				// will blink the green LED if VSYNCs aren't coming in

	// Configure the hardware & set up interrupts

	lpe_init();

	Send_GPad_Packet();			// get cursor on-screen and centered
      
	// ==================================================================================
	// Main loop!
    
	while(1)
	{
		if (blinker++ > 0x8000) {
			blinker = 0;				// as long as we're getting VSYNCs, the VSYNC int
			PORTBINV = 0x0001;			//  handler will keep yanking blinker back to 0

			// If vsyncs (video) has been gone long enough to flip the LED, 
			// the user probably turned off the CMI or pulled the video cable.
			// Go back to the initial cursor state and position, so it won't be
			// potentially confusing when video returns.

			xpos = INIT_XPOS;			// initial cursor position
			ypos = INIT_YPOS;
			show_cursor = 1;			// cursor on by default
		}

		// see if we need to pass on the TOUCH signal from the real LP

/*
		Thanks to Paul Schlusser for figuring out that some CMI UI elements want to 
		see some X-axis jitter on the lightpen!
*/

/*
		// original version w/o jitter

		if( mouse_left_button || (PORTFbits.RF1 == 0) )
			PORTFSET = 0x0001;			// drive HIGH (active, inverted)
		else
			PORTFCLR = 0x0001;			// drive LOW (inactive, inverted)
*/

		if( mouse_left_button || (PORTFbits.RF1 == 0) ) {
			if( mouse_left_button )
				xpos_jitter = 1;		// it was the left mouse button down, add some jitter

			PORTFSET = 0x0001;			// drive HIGH (active, inverted)
		}
		else {
			xpos_jitter = 0;			// button up, TOUCH inactive: no more jitter
			PORTFCLR = 0x0001;			// drive LOW (inactive, inverted)
		}


		USBTasks();						// go poll the mouse
		App_Detect_Device();

		switch(App_State_Mouse)
		{
                case DEVICE_NOT_CONNECTED:
                          	USBTasks();

							PORTBSET = 0x0002;			// Yellow LED OFF

							if(USBHostHID_ApiDeviceDetect()) /* True if report descriptor is parsed with no error */
							{
								App_State_Mouse = DEVICE_CONNECTED;
							}
                    break;

                case DEVICE_CONNECTED:
                          	App_State_Mouse = READY_TO_TX_RX_REPORT;
							
							PORTBCLR = 0x0002;			// Yellow LED ON

							xpos = INIT_XPOS;			// mouse attached, center cursor and
							ypos = INIT_YPOS;
							show_cursor = 1;			// make sure the cursor is visible
                    break;

                case READY_TO_TX_RX_REPORT:
                             if(!USBHostHID_ApiDeviceDetect())
                             {
                                App_State_Mouse = DEVICE_NOT_CONNECTED;
                             }
                             else
                             {
                                App_State_Mouse = GET_INPUT_REPORT;
                             }

                    break;

                case GET_INPUT_REPORT:
                            if(USBHostHID_ApiGetReport(Appl_raw_report_buffer.Report_ID,0,
                                                        Appl_raw_report_buffer.ReportSize, Appl_raw_report_buffer.ReportData))
                            {
                               /* Host may be busy/error -- keep trying */
                            }
                            else
                            {
                                App_State_Mouse = INPUT_REPORT_PENDING;
                            }
                            USBTasks();
                    break;

                case INPUT_REPORT_PENDING:
							if(USBHostHID_ApiTransferIsComplete(&ErrorDriver,&NumOfBytesRcvd))
							{
 								if(ErrorDriver ||(NumOfBytesRcvd != Appl_raw_report_buffer.ReportSize ))
								{
                                  ErrorCounter++ ; 
                                  if(MAX_ERROR_COUNTER <= ErrorDriver)
                                     App_State_Mouse = ERROR_REPORTED;
                                  else
                                     App_State_Mouse = READY_TO_TX_RX_REPORT;
                                }
                                else
                                {
                                  ErrorCounter = 0; 
                                  ReportBufferUpdated = TRUE;
                                  App_State_Mouse = READY_TO_TX_RX_REPORT;

								  last_gpad_x = gpad_x;
								  last_gpad_y = gpad_y;

								  last_show_cursor_gpad = show_cursor_gpad;
								  last_mouse_left_button = mouse_left_button;

                                  App_ProcessInputReport();

								  // if the cursor is on, and something changed, send to CMI
								  // if the cursor just changed on/off state, send to CMI

								  if (	( show_cursor_gpad &&
										  ( (gpad_x != last_gpad_x) || (gpad_y != last_gpad_y) ||
										    (mouse_left_button != last_mouse_left_button) ) )
										||
										( show_cursor_gpad != last_show_cursor_gpad ) ) 
									Send_GPad_Packet();
                                }
                            }
                    break;

               case ERROR_REPORTED:
                    break;
                default:
                    break;

		}
	}
}



/****************************************************************************
  Function:
    void App_ProcessInputReport(void)

  Description:
    This function processes input report received from HID device.

  Precondition:
    None
***************************************************************************/
void App_ProcessInputReport(void)
{
	CHAR data;

   /* process input report received from device */
	USBHostHID_ApiImportData( Appl_raw_report_buffer.ReportData,
								Appl_raw_report_buffer.ReportSize,
                          		Appl_Button_report_buffer, 
								&Appl_Mouse_Buttons_Details );

    USBHostHID_ApiImportData( Appl_raw_report_buffer.ReportData, 
								Appl_raw_report_buffer.ReportSize,
                          		Appl_XY_report_buffer, 
								&Appl_XY_Axis_Details );

#ifndef TUNE_TIMING
	// update lightpen position, if cursor is on

	if (show_cursor) {

		data = Appl_XY_report_buffer[0];	// X axis

		xpos += data;

		if (xpos < 0)
			xpos = 0;
		else if (xpos > MAX_XPOS)
			xpos = MAX_XPOS;

    	data = Appl_XY_report_buffer[1];	// Y axis
		
		ypos += data;

		if (ypos < 0)
			ypos = 0;
		else if (ypos > MAX_YPOS)
			ypos = MAX_YPOS;
	}
#endif

	// update G-Pad position, if cursor is on

	if (show_cursor_gpad) {

		data = Appl_XY_report_buffer[0];	// X axis

		gpad_x += data;

		if (gpad_x < 0)
			gpad_x = 0;
		else if (gpad_x > MAX_GPAD_X)
			gpad_x = MAX_GPAD_X;

    	data = Appl_XY_report_buffer[1];	// Y axis
		
		gpad_y -= data;						// G-Pad Y axis is reversed

		if (gpad_y < 0)
			gpad_y = 0;
		else if (gpad_y > MAX_GPAD_Y)
			gpad_y = MAX_GPAD_Y;
	}

#ifndef TUNE_TIMING
	if(Appl_Button_report_buffer[0])
		mouse_left_button = 1;
	else
		mouse_left_button = 0;

	if(Appl_Button_report_buffer[1]) {		// right button toggles cursor on/off
		show_cursor = !show_cursor;
		show_cursor_gpad = !show_cursor_gpad;
	}
#else
	if(Appl_Button_report_buffer[0]) {
		dump_pos_timing();
		xpos++;
		adjust = 0;
	}	

	if(Appl_Button_report_buffer[1])
		adjust++;
#endif
}
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

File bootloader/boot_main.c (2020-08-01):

/*
********************************************************************************
                                                                                
Software License Agreement                                                      
                                                                                
Copyright © 2008 Microchip Technology Inc. and its licensors.  All         
rights reserved.                                                                
                                                                                
Microchip licenses to you the right to: (1) install Software on a single        
computer and use the Software with Microchip 16-bit microcontrollers and        
16-bit digital signal controllers ("Microchip Product"); and (2) at your        
own discretion and risk, use, modify, copy and distribute the device            
driver files of the Software that are provided to you in Source Code;           
provided that such Device Drivers are only used with Microchip Products         
and that no open source or free software is incorporated into the Device        
Drivers without Microchip's prior written consent in each instance.             
                                                                                
You should refer to the license agreement accompanying this Software for        
additional information regarding your rights and obligations.                   
                                                                                
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
********************************************************************************

 Change History:
  Rev   Description
  ----  -----------------------------------------
  2.7   Updated to include PIC32 support

********************************************************************************
*/

#include "Compiler.h"
#include "GenericTypedefs.h"
#include "HardwareProfile.h"
#include "boot.h"
#include "MDD File System\FSIO.h"
#include "USB\usb.h"
#include "USB\usb_host_msd_scsi.h"


// *****************************************************************************
// *****************************************************************************
// Configuration Bits
// *****************************************************************************
// *****************************************************************************

#define PLL_96MHZ_OFF   0xFFFF
#define PLL_96MHZ_ON    0xF7FF


// *****************************************************************************
// *****************************************************************************
// Configuration Bits
// *****************************************************************************
// *****************************************************************************

// MUST BE THE SAME AS THE APPLICATION CONFIGURATION BITS!

#if defined( __PIC32MX__ )
    #pragma config UPLLEN   = ON            // USB PLL Enabled
    #pragma config FPLLMUL  = MUL_20        // PLL Multiplier
    #pragma config UPLLIDIV = DIV_2         // USB PLL Input Divider
    #pragma config FPLLIDIV = DIV_2         // PLL Input Divider
    #pragma config FPLLODIV = DIV_1         // PLL Output Divider
    #pragma config FPBDIV   = DIV_1         // Peripheral Clock divisor
    #pragma config FWDTEN   = OFF           // Watchdog Timer
    #pragma config WDTPS    = PS1           // Watchdog Timer Postscale
    #pragma config FCKSM    = CSDCMD        // Clock Switching & Fail Safe Clock Monitor
    #pragma config OSCIOFNC = OFF           // CLKO Enable
    #pragma config POSCMOD  = EC            // Primary Oscillator
    #pragma config IESO     = OFF           // Internal/External Switch-over
    #pragma config FSOSCEN  = OFF           // Secondary Oscillator Enable (KLO was off)
    #pragma config FNOSC    = PRIPLL        // Oscillator Selection
    #pragma config CP       = OFF           // Code Protect
    #pragma config BWP      = OFF           // Boot Flash Write Protect
    #pragma config PWP      = OFF           // Program Flash Write Protect
    #pragma config ICESEL   = ICS_PGx2      // ICE/ICD Comm Channel Select
    #pragma config DEBUG    = ON           // Debugger Disabled for Starter Kit
#else
    #error Cannot define configuration bits.
#endif


// Macro used to call main application
/****************************************************************************
  Function:
    int BootApplication ( void )

  Description:
    This macro is used to launch the application.

  Precondition:
    The application image must be correctly programmed into Flash at the 
    appropriate entry point.

  Parameters:
    None

  Returns:
    This call does not normally return.

  Remarks:
    The application's entry point is defined by the APPLICATION_ADDRESS
    macro in the boot_config.h header file.
***************************************************************************/

#define BootApplication()       (((int(*)(void))(APPLICATION_ADDRESS))())
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

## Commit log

2020-08-01 Add files via upload
    Bootloader for the Fairlight CMI lightpen/USB mouse, built using Microchip MPLAB v8.63
    The interface uses a PIC32 microcontroller. The PIC32 Flash memory is divided into 2 sections:
    1. Bootloader (this code)
    2. Application (lightpen emulator)
    At startup this code checks if a USB mass storage device is attached, and if it contains a firmware update file.
    If it does, the file is copied into Flash as the Application. The Bootloader then jumps to the Application code.
    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
2020-08-01 Add files via upload
    Wiring diagram, connector and cabling info.
2020-08-01 Add files via upload
    Original Fairlight CMI lightpen / USB mouse interface PCB, designed with Eagle
    Original aluminum front panel, designed with Front Panel Designer (for Front Panel Express)
    [usb2cmi.brd, usb2cmi.sch, usb2cmi_bom.xlsx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]
2020-08-01 Add files via upload
    Spec for multi-coax cable used for 5-pin XLR cable between CMI mainframe and VDU (monitor)
2020-08-01 Add files via upload
    Version 2 of the Fairlight lightpen / USB mouse interface.
    This version mounts inside the CMI, in an unused mainframe slot.
    +5V power is taken from the ribbon cable to the front panel.
    For a Series I or II, the "Series_I_power" board is needed, because the ribbon cable from the front panel has a different number of pins.
    2 lasercut "wings" are used to hold the board in place in the mainframe slot.
    A rear plate mounts to the bottom pan of the CMI, over 4 of the 8 I/O openings. You can lasercut this plate or use the .fpd file to order a cool aluminum one from Front Panel Express.
    [BOM.xlsx, CMI_Bottom_Pan_Knockout_Cover.brd, Series_I_power.brd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]
2020-08-01 Add files via upload
    Corrected error in one comment.
    [cmi_mouse.c]
2020-08-01 Add files via upload
    Pre-built images of the 2 needed hexfiles.
    Use the Microchip tools to flash bootloader.hex into the PIC32.
    Put cmimouse.hex on a USB thumbdrive (formatted with a DOS/FAT filesystem).
    Plug the thumbdrive into the interface USB port and power up the board.
    You should see the leds blink back and forth, then the cmimouse.hex file will be copied from the thumbdrive to the PIC32 flash.
    You'll see the LEDs change their flashing pattern when the code is flashed and started.
    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
2020-08-02 Delete cmi_mouse_excellon.cam
    holdover from old version of board.
2020-08-02 Delete cmi_mouse_gerb274x.cam
    Holdover from old version of board.
2023-01-05 Update README.md
    Added link to OSHPark for PCB
2023-01-05 Add files via upload
    added PDFs of schematic and PCB.
2023-01-05 Update README.md
    added link to v1 PCB
2024-09-11 Added Front Panel Designer and DXF files for front panel
    Added Front Panel Designer and DXF files for front panel.
    I used Front Panel Designer to create the aluminum plate that the PCB mounts to, and used their service to manufacture it.
    I exported a DXF, which can be used to reproduce the panel with other tools.
    [USB2CMI_log.dxf]
2025-11-17 Add support for 2025/REV3 hardware.
    2025 version of the interface adds a switch to let the user select one of two cursor shapes:
    A: Classic 2010 Interface 3-line arrow cursor
    B: Large Crescent cursor, emulating cursor seen with the original lightpen

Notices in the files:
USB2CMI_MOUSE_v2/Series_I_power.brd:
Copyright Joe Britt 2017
